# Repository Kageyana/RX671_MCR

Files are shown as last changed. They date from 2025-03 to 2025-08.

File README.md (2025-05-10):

# 初期設定
1. ワークスペースのパスは2バイト文字禁止
2. e2studio プロジェクトの設定→C/C++ビルド→設定<br>ツール設定タブ→Compiler→Includesに<br>
```"${workspace_loc:/${ProjName}/inc}"```<br>
を追加
3. Renesas Extensions for Visual Studio Codeを使う場合<br>
	1. 下記ページを参考に拡張機能をインストールする
	https://qiita.com/y_toyoyama/items/98b7511f9f95343f7a40<br>
	2. launch.json<br>
	serverParametersはデバッガ情報をLLMに渡して整形してもらうと楽
	3. CMakeLists.txt<br>
	CMAKE_CURRENT_SOURCE_DIRに```"inc/*.h"```を追加<br>
	CMAKE_CXX_FLAGSにコンパイラオプションを追加する<br>
	CMAKE_EXE_LINKER_FLAGSにリンカオプションを追加する
	4. .clangd<br>
	下記リポジトリを参考に.clangdとc_cpp_intellisense_helper.hを追加する<br>
	https://github.com/NoMaY-jp/Renesas_VSCode_Extensions_tips_for_Renesas_CC_compilers.git

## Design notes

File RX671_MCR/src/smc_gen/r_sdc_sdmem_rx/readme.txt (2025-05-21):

r_sdc_sdmem_rx (SD Mode SD Memory Card Driver)
=======================

Overview
--------
This driver is a block type device driver to control the SD mode SD memory card using SD Host Interface (SDHI).

Features
--------
* SD Specifications Part 1 Physical Layer Simplified Specifications version 6.00 (SD memory control commands are supported)
* Block type device driver which takes 1 block to be 512 bytes
* SD mode (4 bits) is supported.
* Default speed mode are supported.
* Standard capacity SD memory cards (SDSC) and high-capacity SD memory cards (SDHC, SDXC) are supported.
* Only user areas are supported.
* Only CD pin detection is supported.

File Structure
--------------
r_sdc_sdmem_rx
|   r_sdc_sd_rx_if.h
|   readme.txt
|
+---doc
|   |
|   +---en
|   |   r01an4233ej0301-rx-sdmemory.pdf
|   |
|   +---ja
|       r01an4233jj0301-rx-sdmemory.pdf
|
|
+---src
    |   r_sdc_sd_cd.c
    |   r_sdc_sd_cmd.c
    |   r_sdc_sd_config.c
    |   r_sdc_sd_initialize.c
    |   r_sdc_sd_int.c
    |   r_sdc_sd_open.c
    |   r_sdc_sd_rx_private.h
    |   r_sdc_sd_trans.c
    |   r_sdc_sd_util.c
    |   r_sdc_sd_wrapper.c
    |
    +---mem
            r_sdc_sdmem_initialize.c
            r_sdc_sdmem_param.c
            r_sdc_sdmem_read.c
            r_sdc_sdmem_util.c
            r_sdc_sdmem_wrapper.c
            r_sdc_sdmem_write.c

r_config
    r_sdc_sd_rx_config.h

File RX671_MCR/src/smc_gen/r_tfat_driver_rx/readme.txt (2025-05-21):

r_tfat_driver_rx
=========

Overview
--------
This memory driver interface connects TFAT and Device Drivers(USB etc).
TFAT is a FAT file system which just requires small memory.
TFAT is based on FatFs.
<br/>
Please refer to the
 https://www.renesas.com/mw/tfat

Features
--------
* This memory driver interface connects TFAT and Device Drivers(USB etc).

File Structure
--------------
r_config
    r_tfat_driver_rx_config.h

r_tfat_driver_rx
|   readme.txt
|   r_tfat_driver_rx_if.h
|
+---doc
|   |
|   +---en
|   |   r20an0335ej0261-rx-tfat.pdf
|   +---ja
|       r20an0335jj0261-rx-tfat.pdf
+---src
    |   r_tfat_drv_if.c
    |   r_tfat_drv_if_dev.h
    |
    +---device
        |
        +---sdmem
        |      r_tfat_drv_if_sdmem.c
        +---spi_sdmem
        |      r_tfat_drv_if_spi_sdmem.c
        +---usb
        |      r_tfat_drv_if_usb.c
        +---usb_mini
        |      r_tfat_drv_if_usb_mini.c
        +---mmc
        |      r_tfat_drv_if_mmc.c
        +---serial_flash
               r_tfat_drv_if_flash.c

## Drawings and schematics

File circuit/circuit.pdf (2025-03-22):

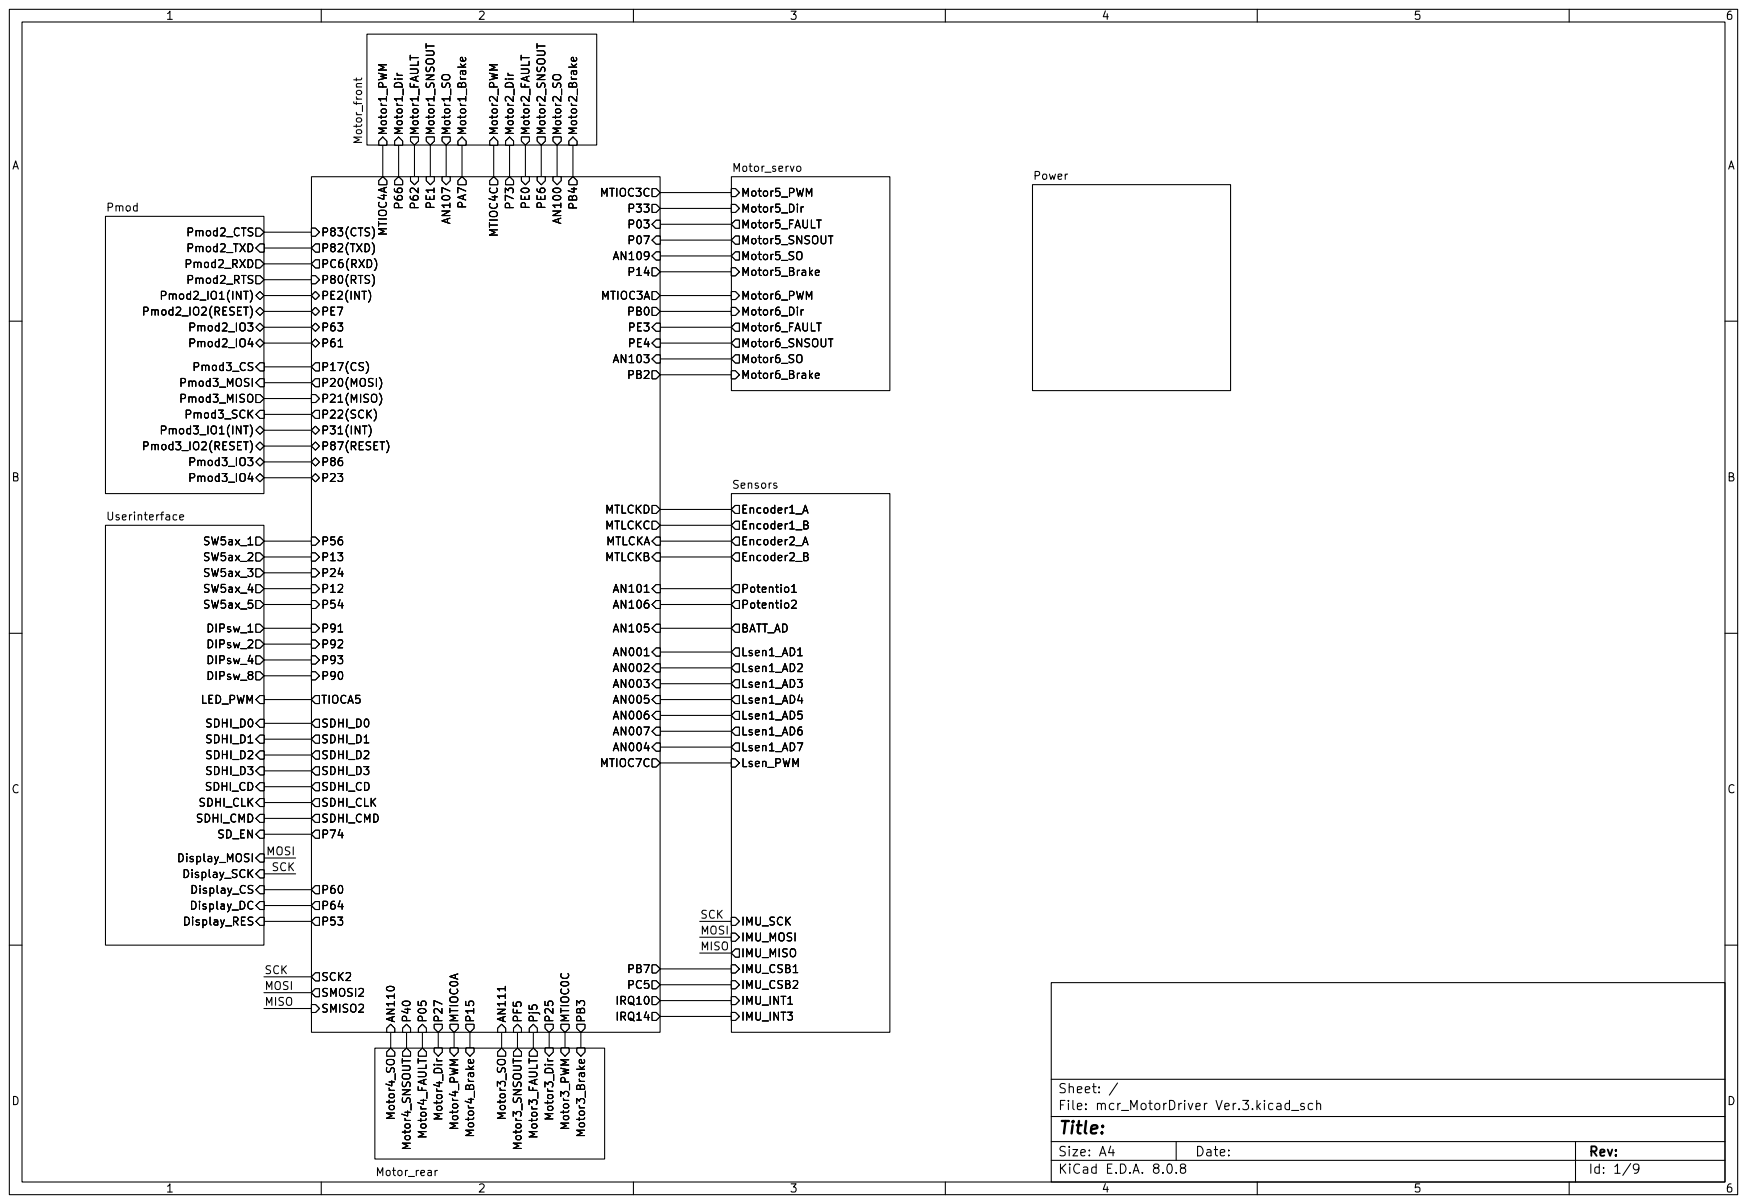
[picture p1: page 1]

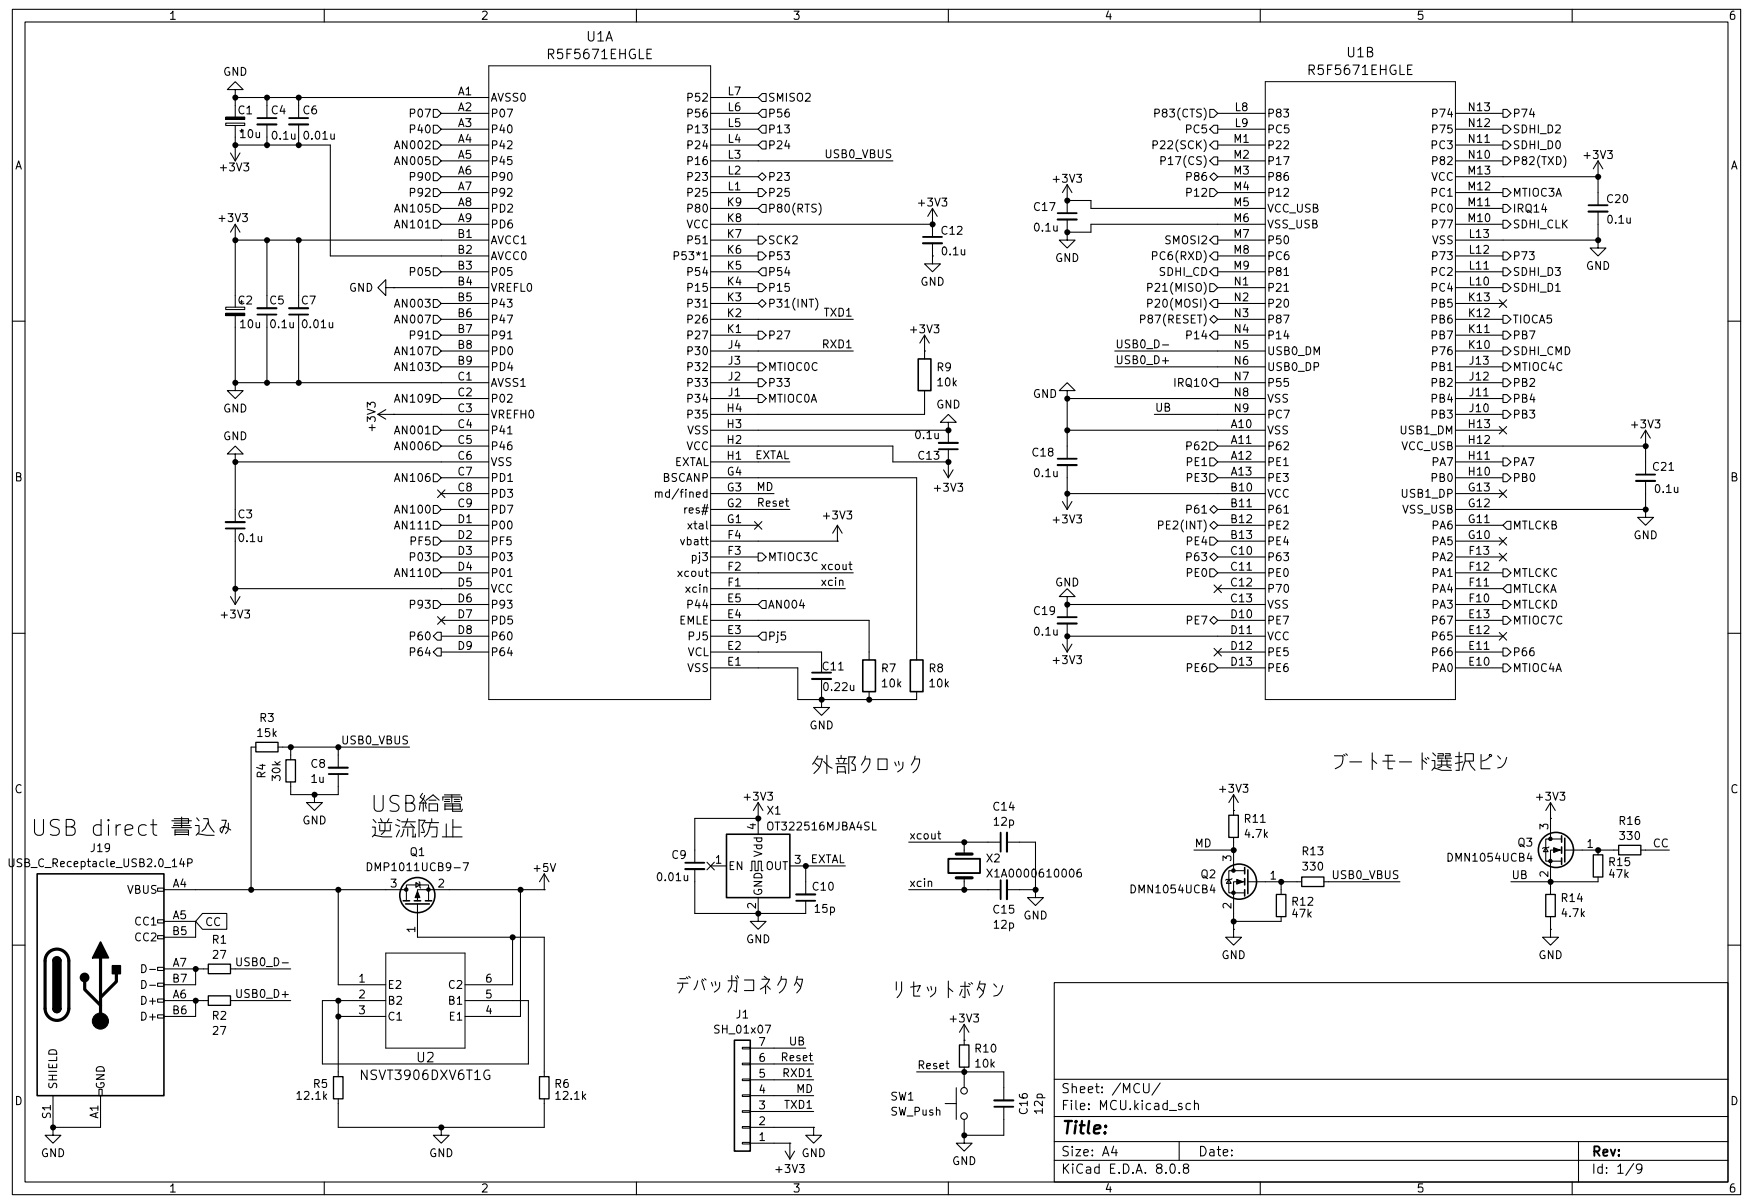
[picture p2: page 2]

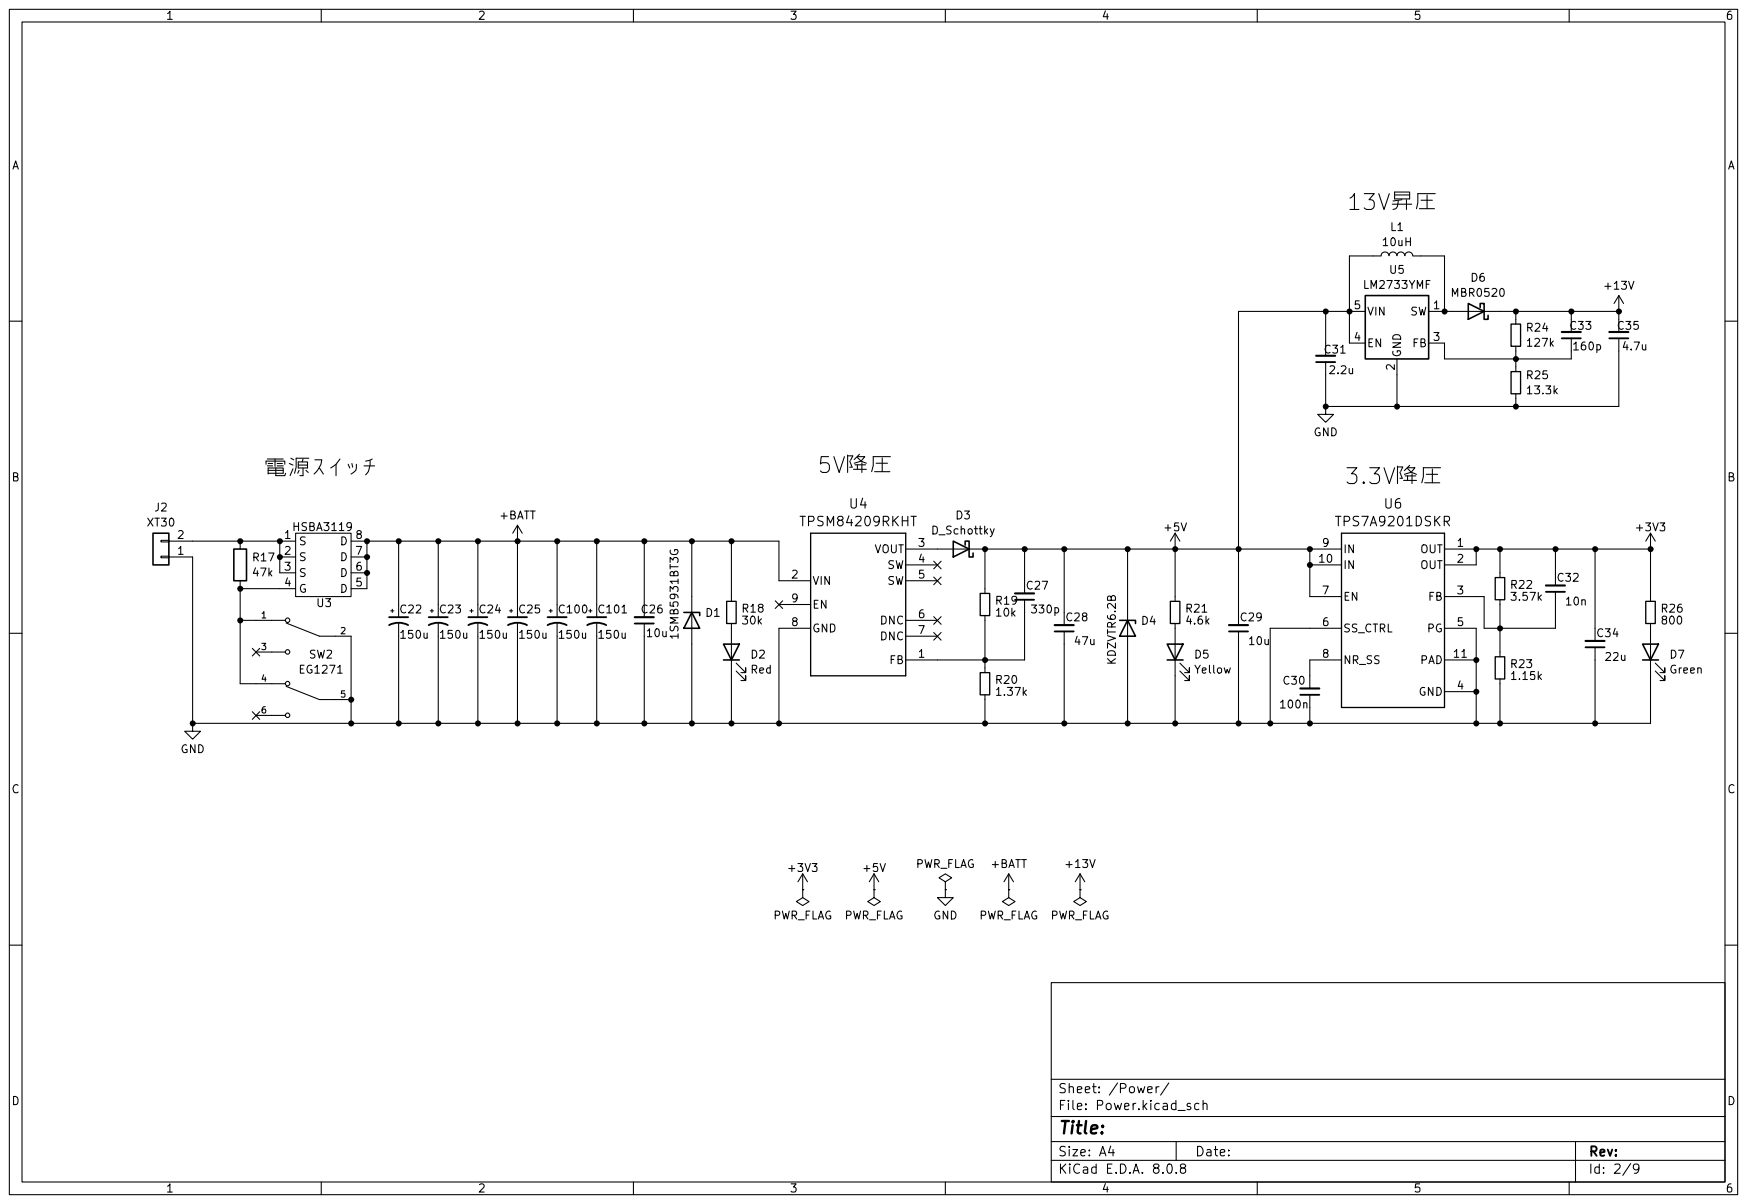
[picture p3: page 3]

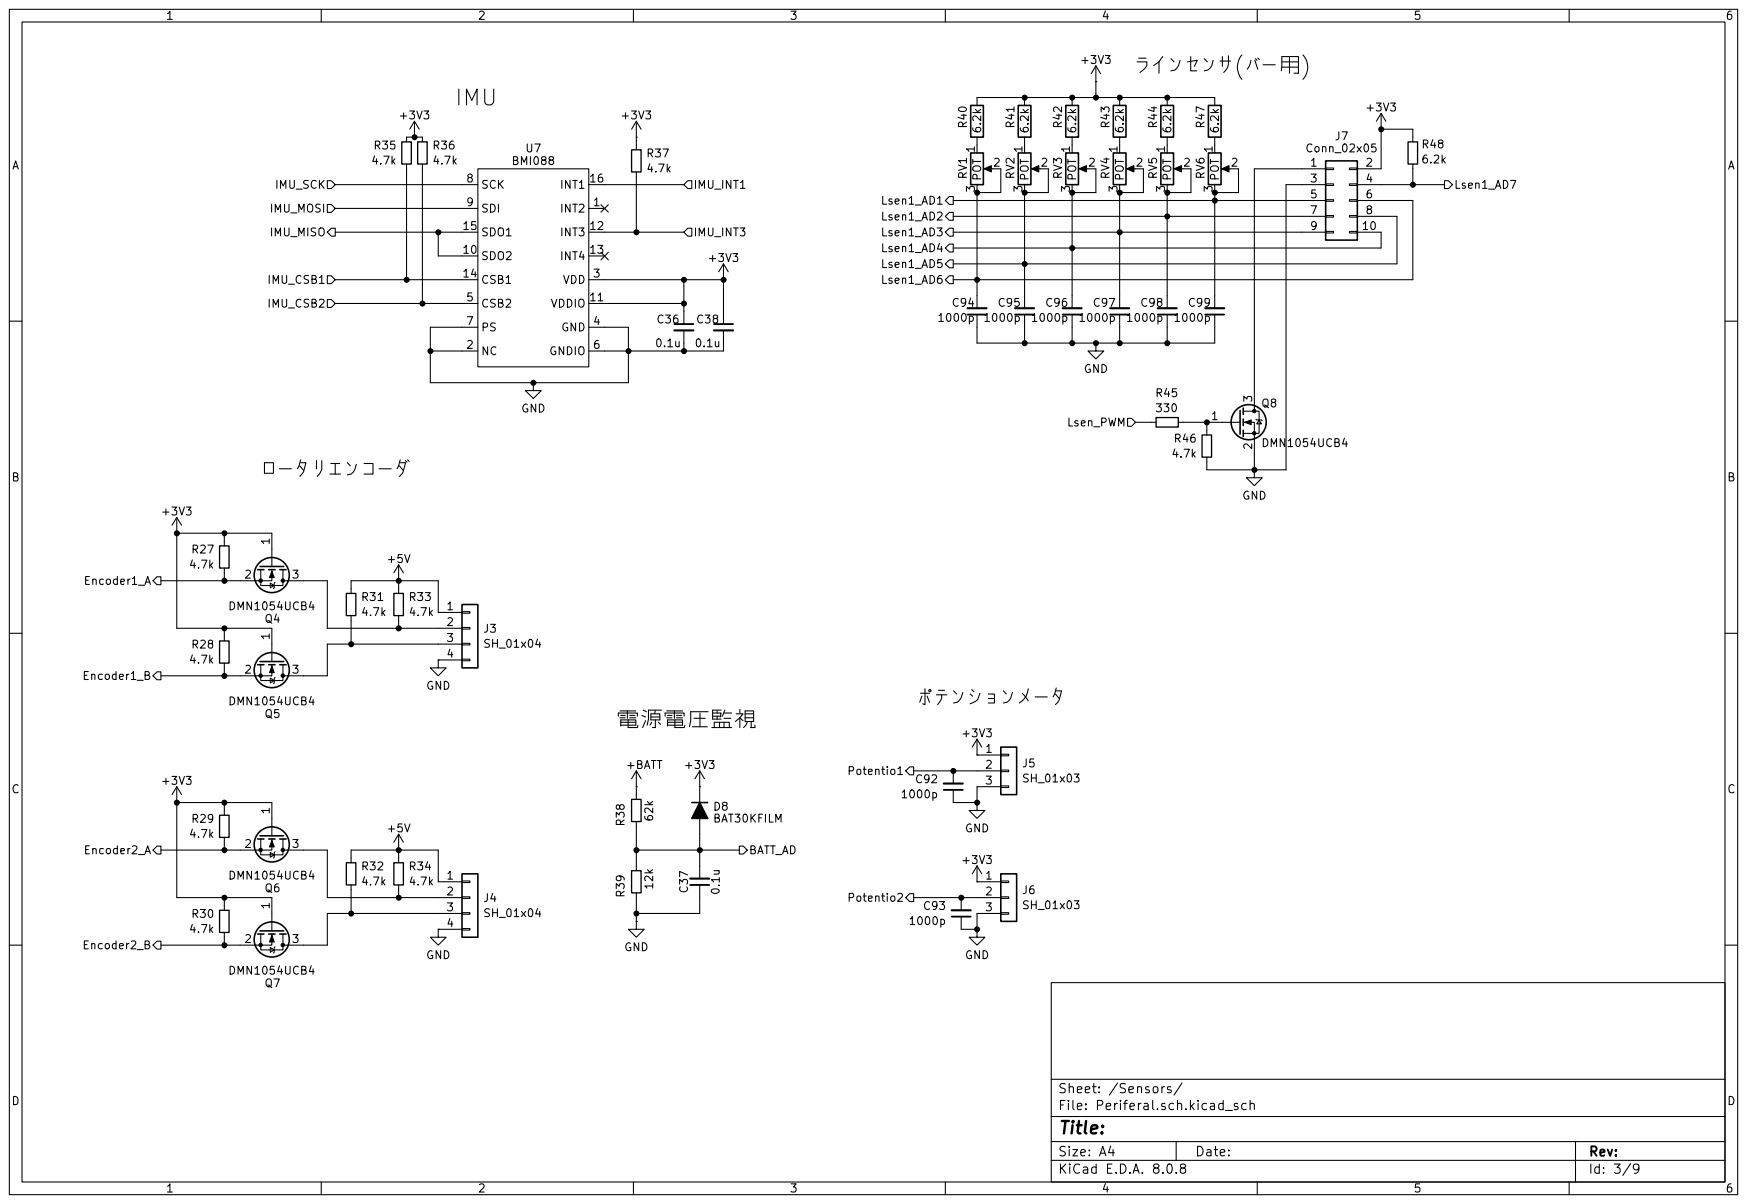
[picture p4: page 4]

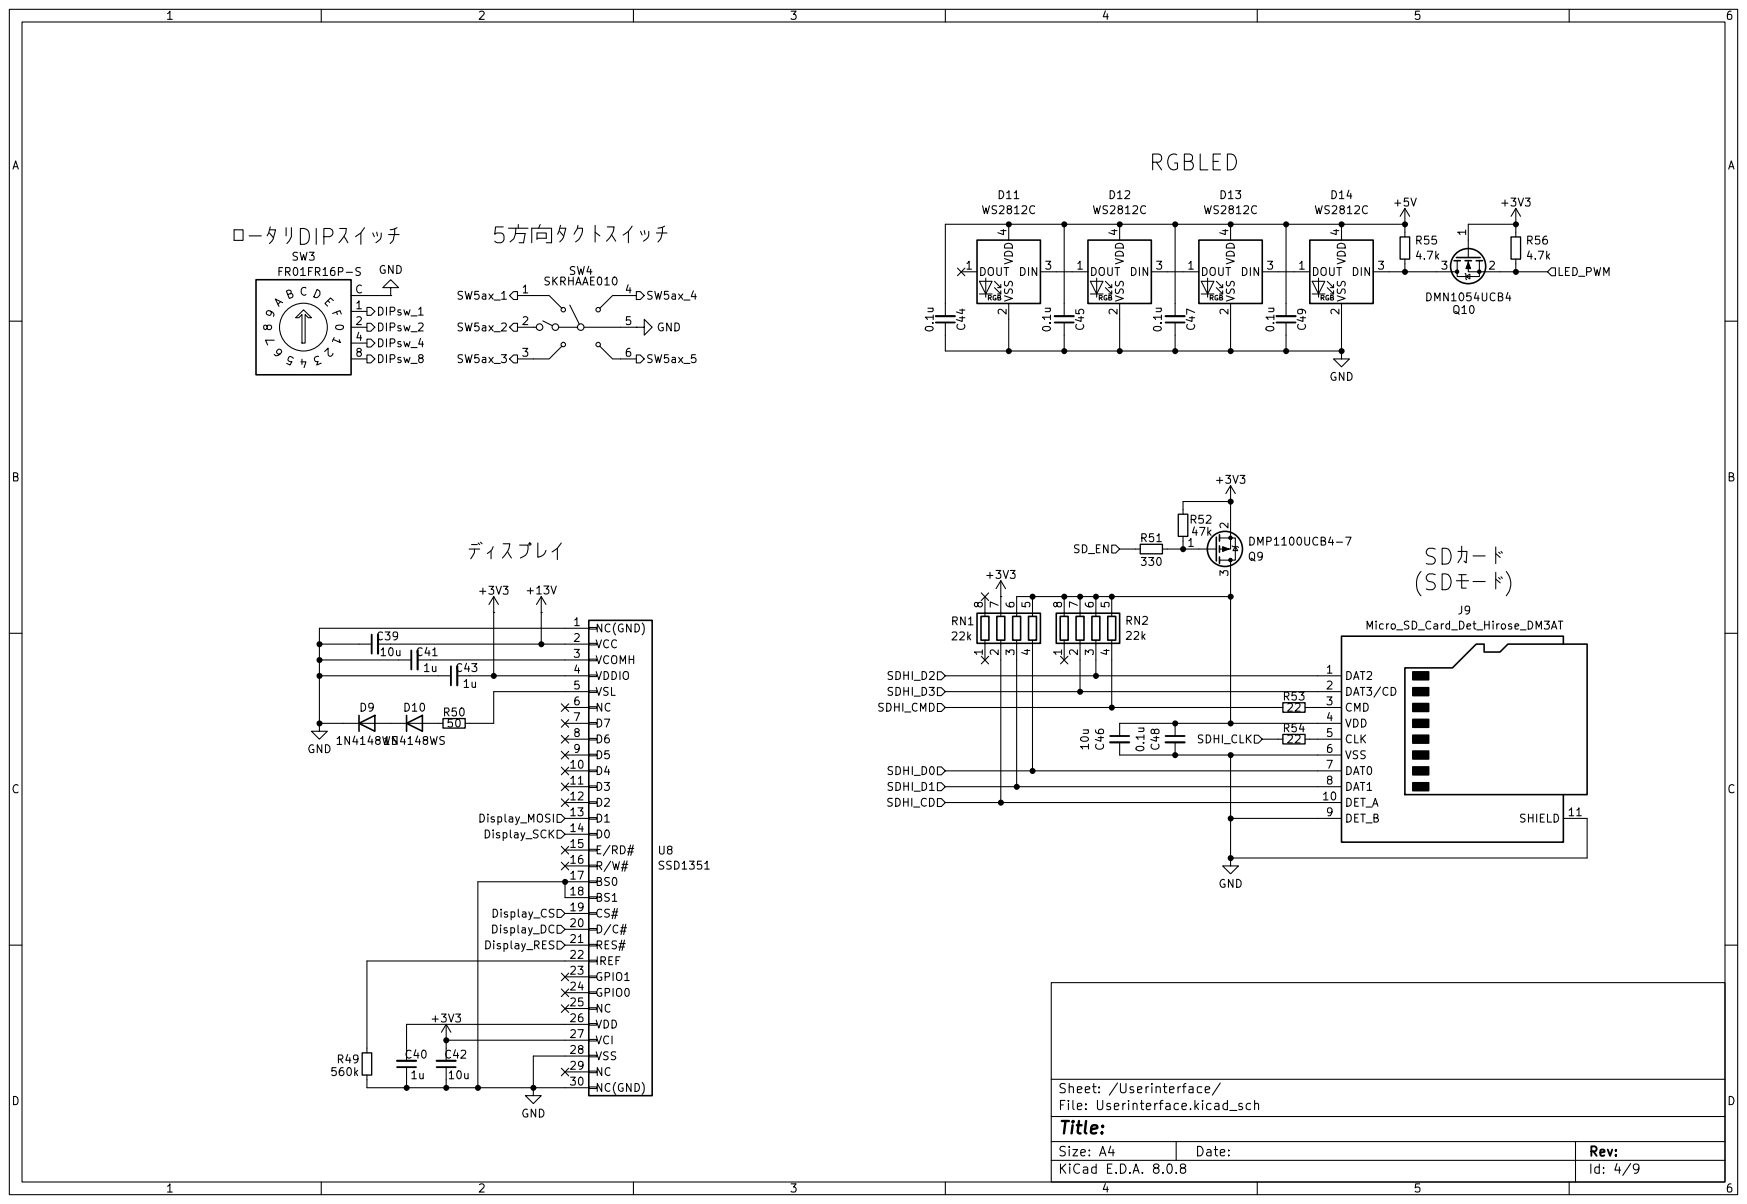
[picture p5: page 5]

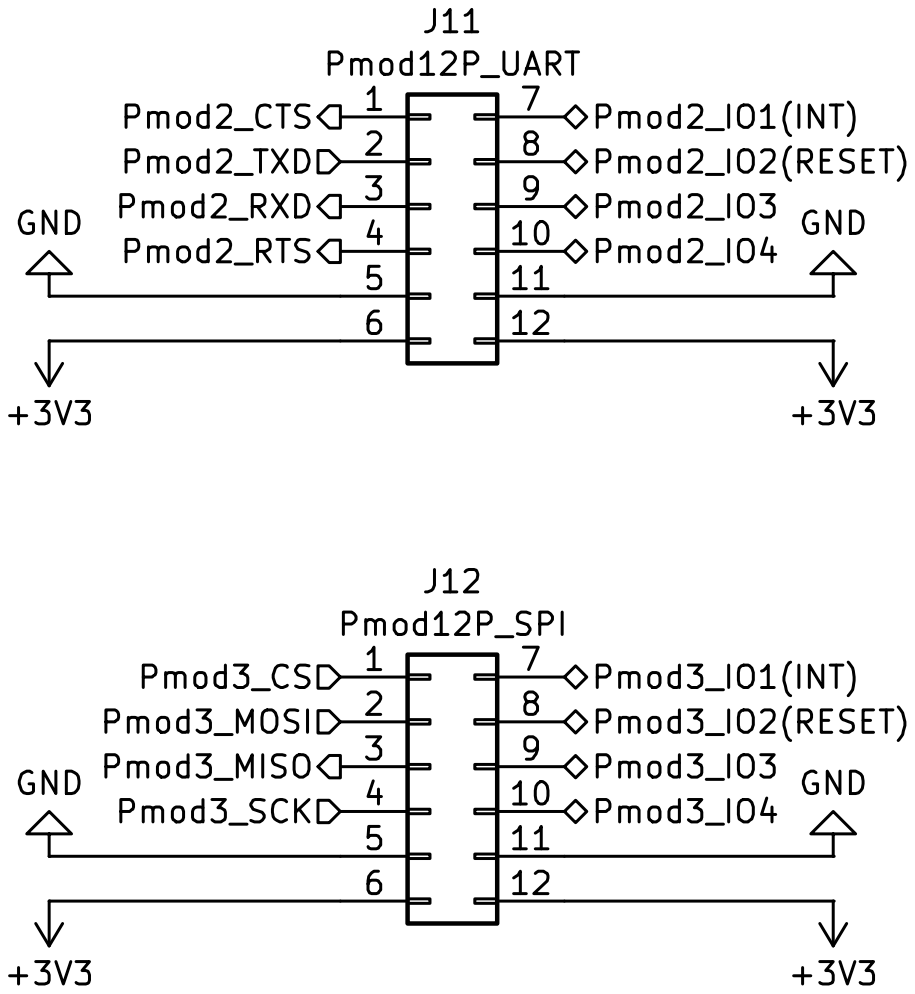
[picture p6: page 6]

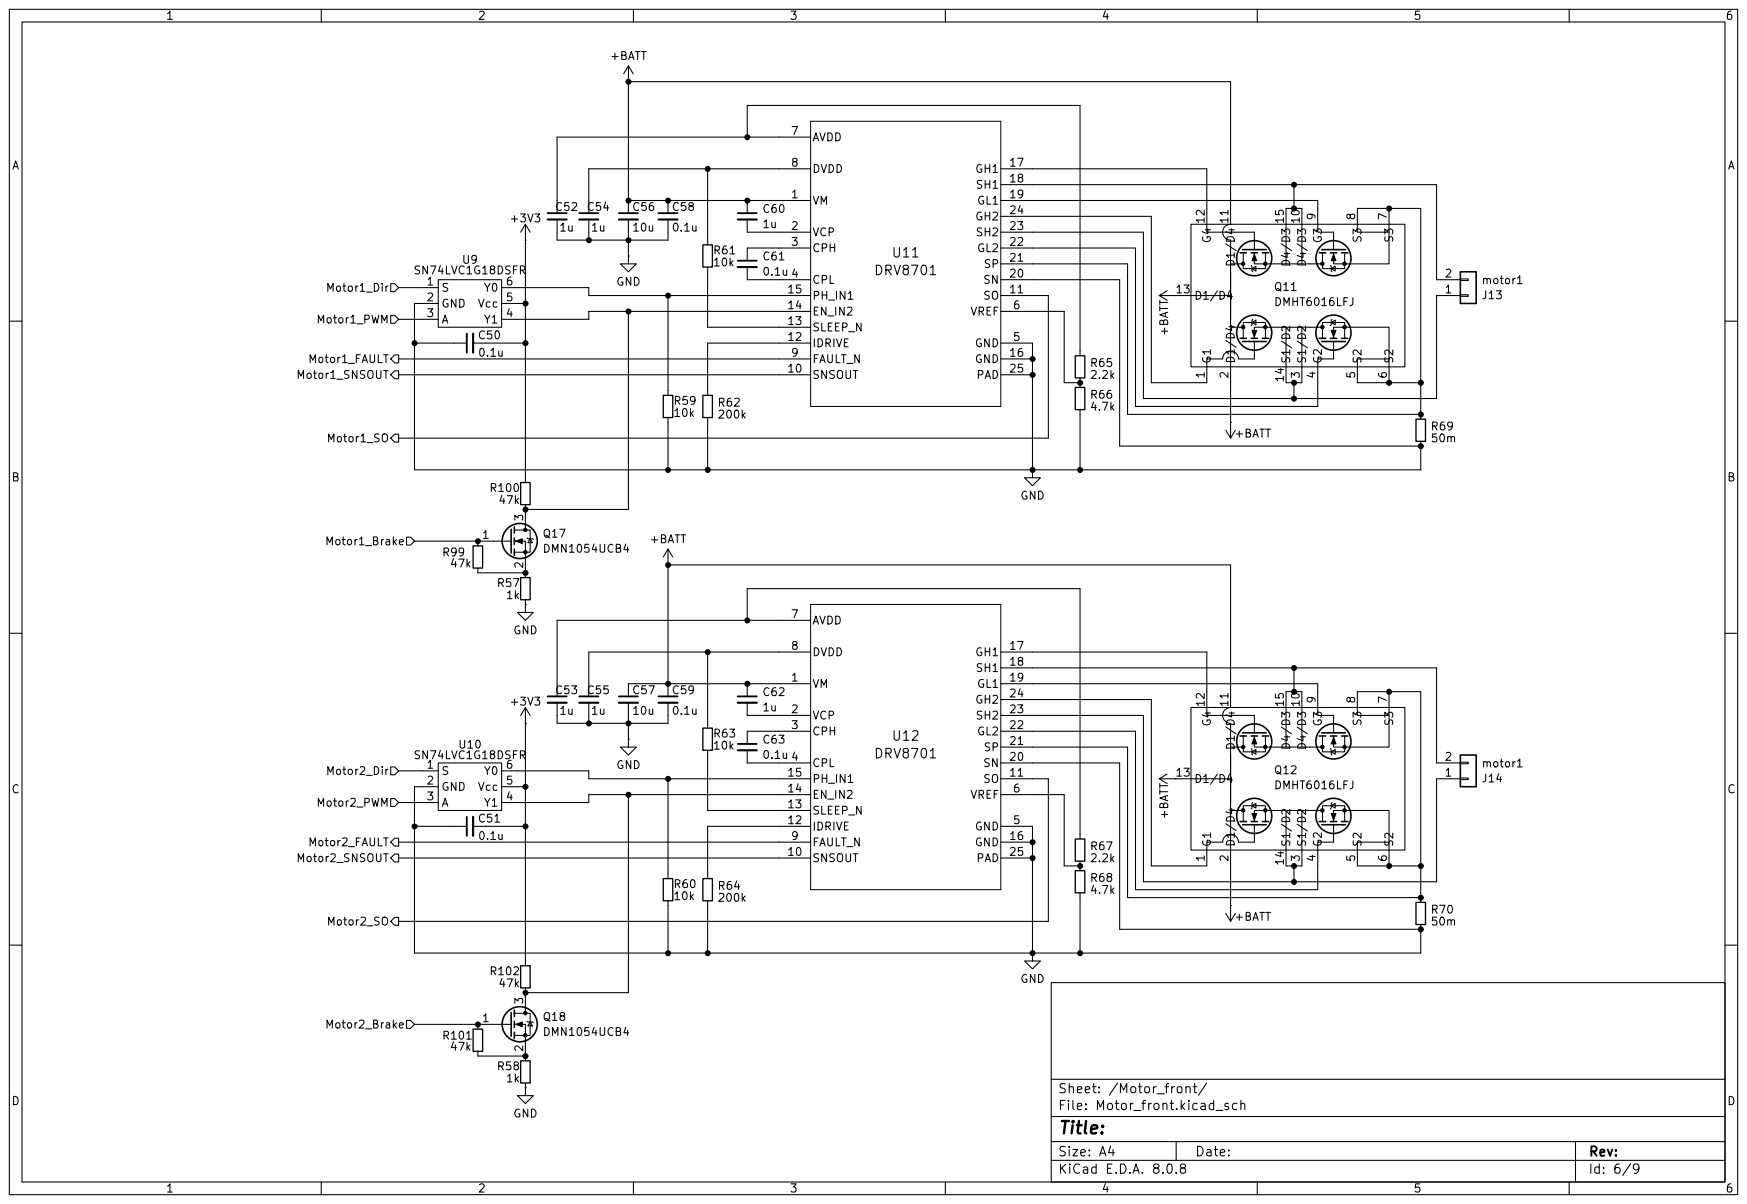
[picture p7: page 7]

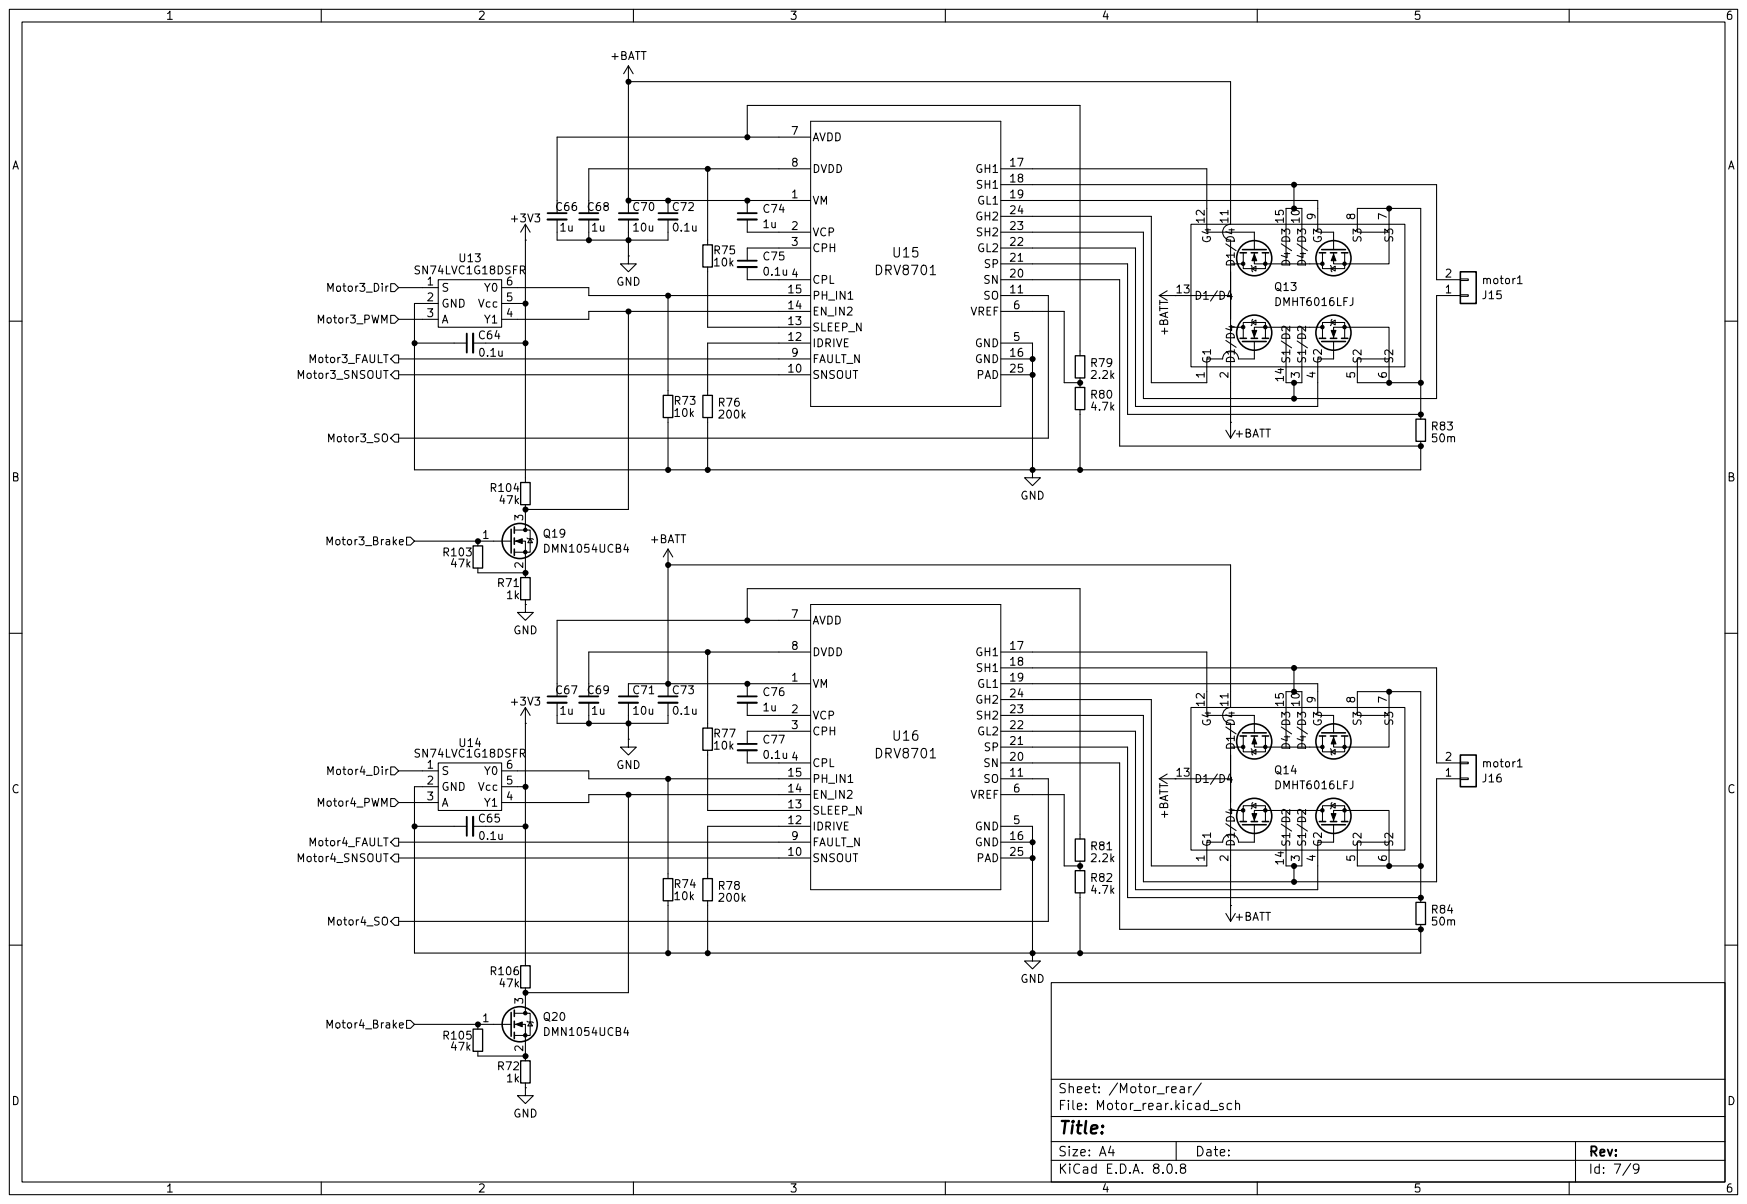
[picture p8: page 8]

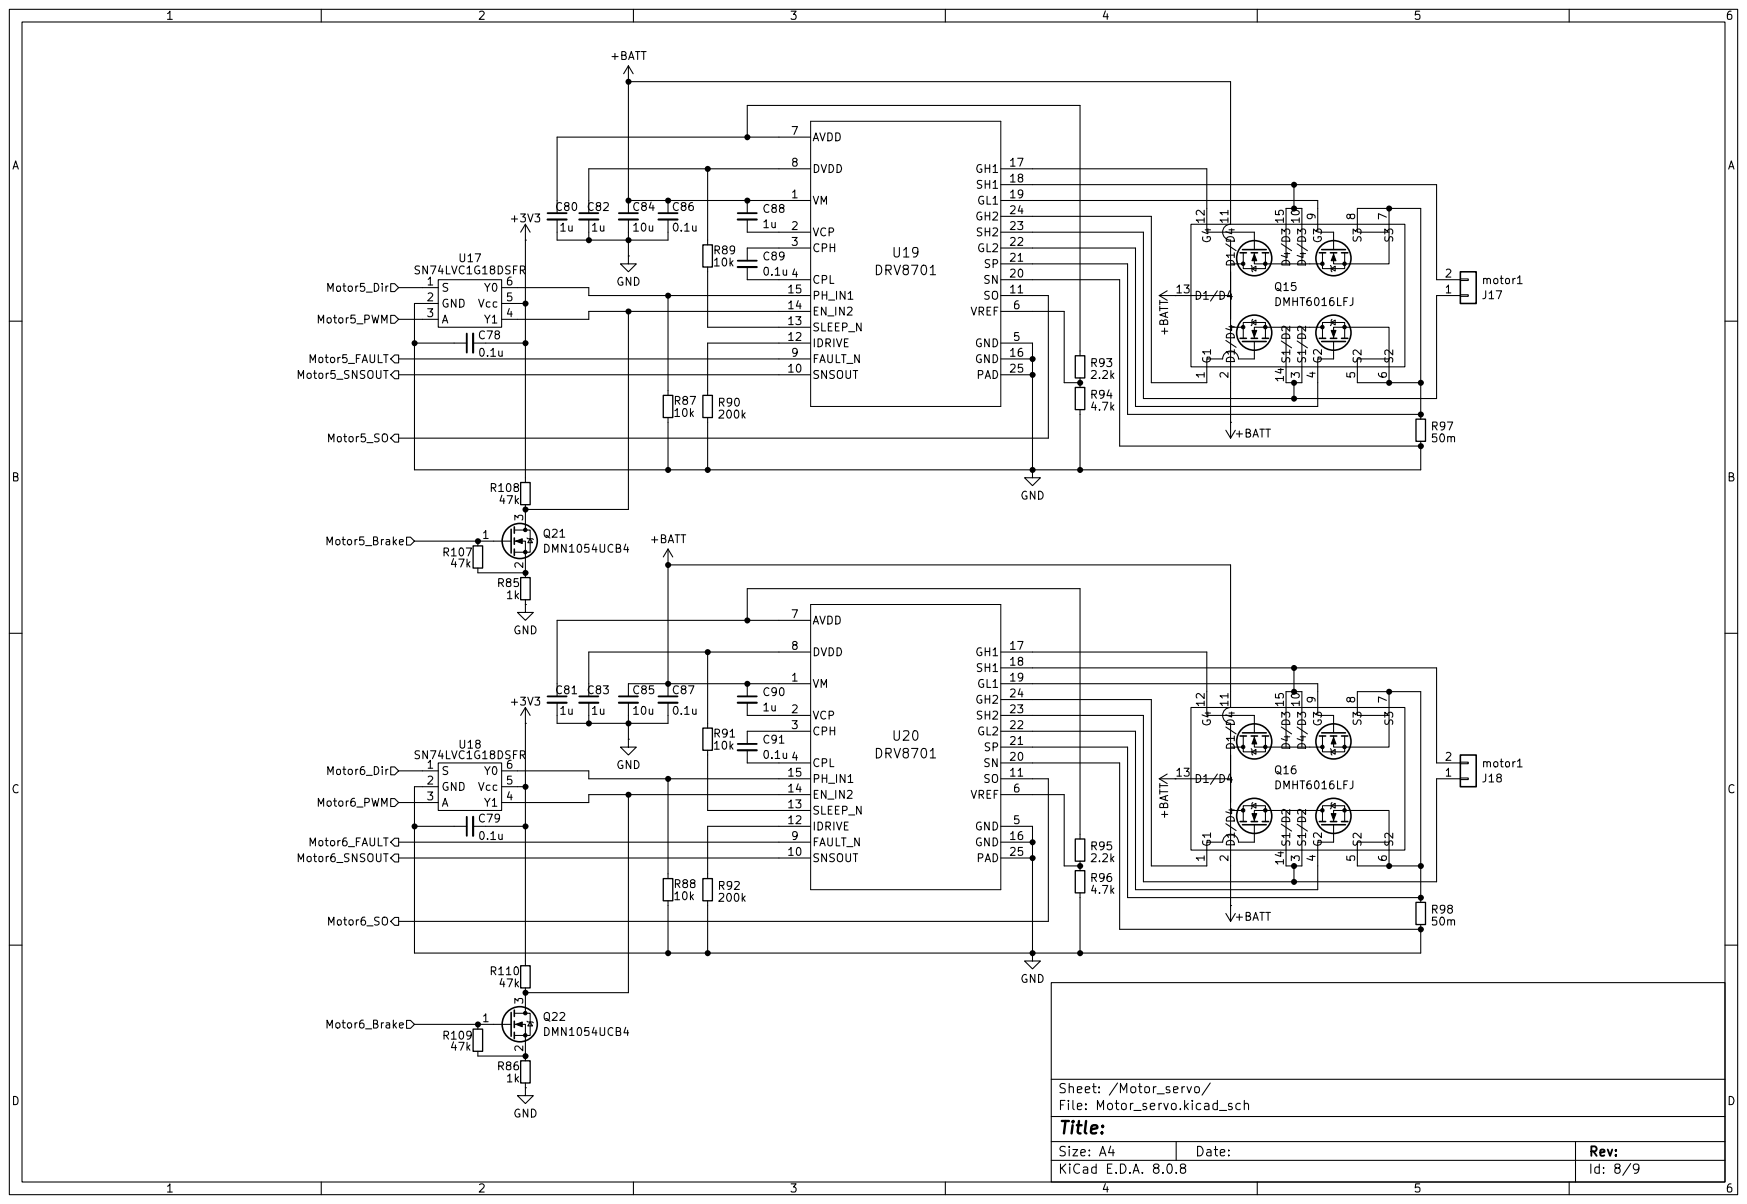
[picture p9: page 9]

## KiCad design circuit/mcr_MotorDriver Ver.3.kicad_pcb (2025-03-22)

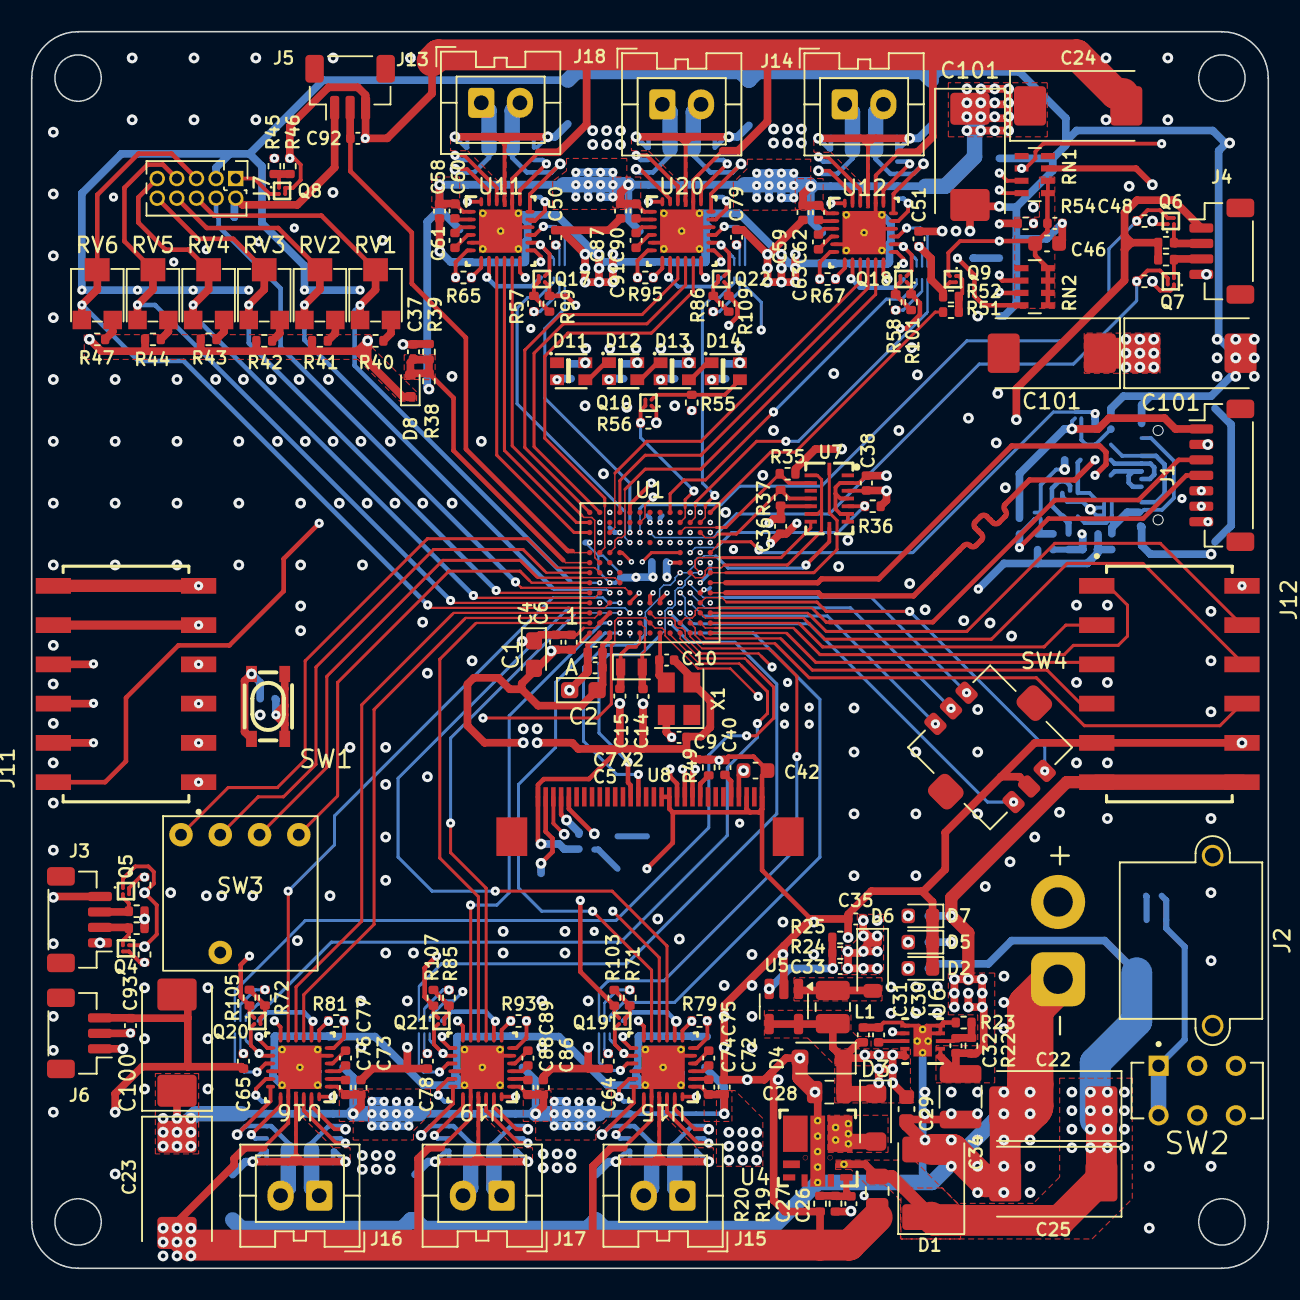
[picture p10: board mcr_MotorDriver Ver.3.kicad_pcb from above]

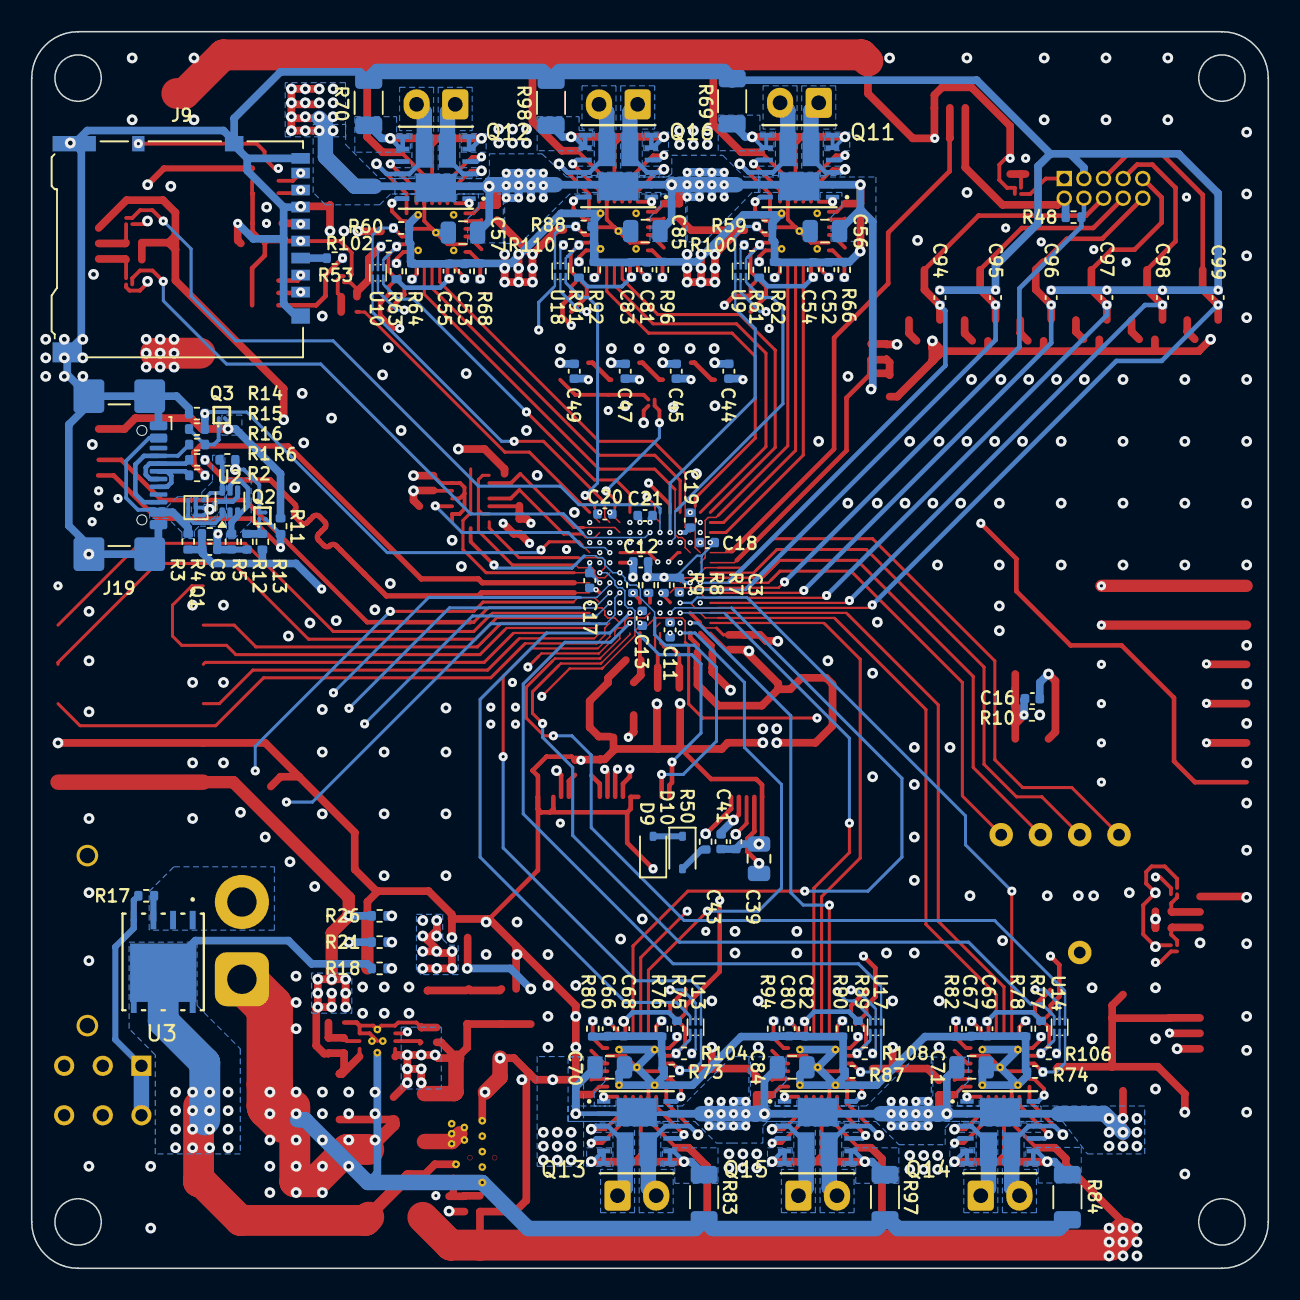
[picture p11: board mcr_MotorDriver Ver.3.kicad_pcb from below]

Board: 6 copper layers, 80.0 x 80.0 mm, 301 parts (122 on the bottom side), 268 nets.

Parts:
C1, C2: 10u; CP_EIA-2012-12_Kemet-R
C3, C4, C5, C12, C13, C17, C18, C19, C20, C21, C36, C37, C38, C44, C45, C47, C48, C49, C50, C51, C58, C59, C61, C63, C64, C65, C72, C73, C75, C77, C78, C79, C86, C87, C89, C91: 0.1u; C_0402_1005Metric
C6, C7, C9: 0.01u; C_0402_1005Metric
C8, C40, C41, C43, C52, C53, C54, C55, C60, C62, C66, C67, C68, C69, C74, C76, C80, C81, C82, C83, C88, C90: 1u; C_0402_1005Metric
C10: 15p; C_0402_1005Metric
C11: 0.22u; C_0402_1005Metric
C14, C15, C16: 12p; C_0402_1005Metric
C22, C23, C24, C25, C100, C101, C101#2, C101#3: 150u; CP_EIA-7343-31_Kemet-D
C26, C39, C56, C57, C70, C71, C84, C85: 10u; C_0805_2012Metric
C27: 330p; C_0402_1005Metric
C28: 47u; C_0805_2012Metric
C29, C42, C46: 10u; C_0603_1608Metric
C30: 100n; C_0402_1005Metric
C31: 2.2u; C_0402_1005Metric
C32: 10n; C_0402_1005Metric
C33: 160p; C_0402_1005Metric
C34: 22u; C_1210_3225Metric
C35: 4.7u; C_0402_1005Metric
C92, C93, C94, C95, C96, C97, C98, C99: 1000p; C_0402_1005Metric
D1: 1SMB5931BT3G; D_2114_3652Metric
D2: Red; LED_0603_1608Metric
D3: D_Schottky; D_SOD-123W
D4: KDZVTR6.2B; D_SOD-123F
D5: Yellow; LED_0603_1608Metric
D6: MBR0520; D_SOD-123
D7: Green; LED_0603_1608Metric
D8: BAT30KFILM; D_SOD-523
D9, D10: 1N4148WS; D_SOD-323
D11, D12, D13, D14: WS2812C; WS2812C-2020
J1: SH_01x07; JST_SH_BM07B-SRSS-TB_1x07-1MP_P1.00mm_Vertical
J2: XT30; AMASS_XT30PW-M_1x02_P2.50mm_Horizontal
J3, J4: SH_01x04; JST_SH_BM04B-SRSS-TB_1x04-1MP_P1.00mm_Vertical
J5, J6: SH_01x03; JST_SH_BM03B-SRSS-TB_1x03-1MP_P1.00mm_Vertical
J7: Conn_02x05; FTSH-105-01-F-D-K
J9: Micro_SD_Card_Det_Hirose_DM3AT; microSD_HC_Hirose_DM3AT-SF-PEJM5
J11: Pmod12P_UART; Pmod_2x06_P2.54mm
J12: Pmod12P_SPI; Pmod_2x06_P2.54mm
J13, J14, J15, J16, J17, J18: motor1; JST_XA_B02B-XASK-1_1x02_P2.50mm_Vertical
J19: USB_C_Receptacle_USB2.0_14P; USB_C_Receptacle_GCT_USB4110
L1: 10uH; L_1008_2520Metric
Q1: DMP1011UCB9-7
Q2, Q3, Q4, Q5, Q6, Q7, Q8, Q10, Q17, Q18, Q19, Q20, Q21, Q22: DMN1054UCB4
Q9: DMP1100UCB4-7; DMN1054UCB4
Q11, Q12, Q13, Q14, Q15, Q16: DMHT6016LFJ; V-DFN5045-12_DIO
R1, R2: 27; R_0402_1005Metric
R3: 15k; R_0402_1005Metric
R4, R18: 30k; R_0402_1005Metric
R5, R6: 12.1k; R_0402_1005Metric
R7, R8, R9, R10, R19, R59, R60, R61, R63, R73, R74, R75, R77, R87, R88, R89, R91: 10k; R_0402_1005Metric
R11, R14, R27, R28, R29, R30, R31, R32, R33, R34, R35, R36, R37, R46, R55, R56, R66, R68, R80, R82, R94, R96: 4.7k; R_0402_1005Metric
R12, R15, R17, R52, R99, R100, R101, R102, R103, R104, R105, R106, R107, R108, R109, R110: 47k; R_0402_1005Metric
R13, R16, R45, R51: 330; R_0402_1005Metric
R20: 1.37k; R_0402_1005Metric
R21: 4.6k; R_0402_1005Metric
R22: 3.57k; R_0402_1005Metric
R23: 1.15k; R_0402_1005Metric
R24: 127k; R_0402_1005Metric
R25: 13.3k; R_0402_1005Metric
R26: 800; R_0402_1005Metric
R38: 62k; R_0402_1005Metric
R39: 12k; R_0402_1005Metric
R40, R41, R42, R43, R44, R47, R48: 6.2k; R_0402_1005Metric
R49: 560k; R_0402_1005Metric
R50: 50; R_0402_1005Metric
R53, R54: 22; R_0402_1005Metric
R57, R58, R71, R72, R85, R86: 1k; R_0402_1005Metric
R62, R64, R76, R78, R90, R92: 200k; R_0402_1005Metric
R65, R67, R79, R81, R93, R95: 2.2k; R_0402_1005Metric
R69, R70, R83, R84, R97, R98: 50m; R_1206_3216Metric
RN1, RN2: 22k; R_Array_Concave_4x0603
RV1, RV2, RV3, RV4, RV5, RV6: POT; ST-32EA
SW1: SW_Push; SKRPABE010
SW2: EG1271; SW_EG1271
SW3: FR01FR16P-S
SW4: SKRHAAE010
U1: R5F5671EHGLE; R5F5671EHGLE-20
U2: NSVT3906DXV6T1G; SOT-563
U3: HSBA3119; IRFH7084TRPBF_INF
U4: TPSM84209RKHT
U5: LM2733YMF; SOT-23-5
U6: TPS7A9201DSKR; TPS7A9201DSKT
U7: BMI088
U8: SSD1351
U9, U10, U13, U14, U17, U18: SN74LVC1G18DSFR
U11, U12, U15, U16, U19, U20: DRV8701
X1: OT322516MJBA4SL; Oscillator_SMD_Abracon_ASE-4Pin_3.2x2.5mm
X2: X1A0000610006; Crystal_SMD_2012-2Pin_2.0x1.2mm

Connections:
+3V3: C1.1, C2.1, C3.1, C4.2, C5.2, C6.2, C7.2, C9.1, C12.1, C13.1, C17.1, C18.2, C19.2, C20.1, C21.1, C32.2, C34.2, C36.1, C38.1, C42.2, C43.2, C50.2, C51.2, C64.2, C65.2, C78.2, C79.2, D8.1 (K), J1.1, J5.1, J6.1, J7.2, J11.6, J11.12, J12.6, J12.12, Q3.3 (D), Q4.1 (G), Q5.1 (G), Q6.1 (G), Q7.1 (G), Q9.2 (S), Q10.1 (G), R9.1, R10.2, R11.2, R22.2, R26.2, R27.2, R28.2, R29.2, R30.2, R35.1, R36.2, R37.2, R40.1, R41.1, R42.1, R43.1, R44.1, R47.1, R48.1, R52.2, R56.2, R100.2, R102.2, R104.2, R106.2, R108.2, R110.2, RN1.7 (R2.2), U1.B1 (AVCC1), U1.B2 (AVCC0), U1.B10 (VCC), U1.C3 (VREFH0), U1.D5 (VCC), U1.D11 (VCC), U1.F4 (vbatt), U1.H2 (VCC), U1.H12 (VCC_USB), U1.K8 (VCC), U1.M5 (VCC_USB), U1.M13 (VCC), U6.1 (OUT), U6.2 (OUT), U7.3 (VDD), U7.11 (VDDIO), U8.4 (VDDIO), U8.27 (VCI), U9.5 (Vcc), U10.5 (Vcc), U13.5 (Vcc), U14.5 (Vcc), U17.5 (Vcc), U18.5 (Vcc), X1.4 (Vdd)
+5V: C27.2, C28.2, C29.2, C31.2, C44.2, C45.2, C47.2, C49.2, D3.1 (K), D4.1 (K), D11.4 (VDD), D12.4 (VDD), D13.4 (VDD), D14.4 (VDD), J3.1, J4.1, L1.1, Q1.2 (S), R19.2, R21.2, R31.2, R32.2, R33.2, R34.2, R55.2, U2.4 (E1), U5.4 (EN), U5.5 (VIN), U6.7 (EN), U6.9 (IN), U6.10 (IN)
+13V: C33.2, C35.2, C39.2, D6.1 (K), R24.2, U8.2 (VCC)
+BATT: C22.1, C23.1, C24.1, C25.1, C26.2, C56.1, C57.1, C58.1, C59.1, C60.1, C62.1, C70.1, C71.1, C72.1, C73.1, C74.1, C76.1, C84.1, C85.1, C86.1, C87.1, C88.1, C90.1, C100.1, C101.1, C101#2.1, C101#3.1, D1.1 (K), Q11.2 (D1/D4), Q11.11 (D1/D4), Q11.13 (D1/D4), Q12.2 (D1/D4), Q12.11 (D1/D4), Q12.13 (D1/D4), Q13.2 (D1/D4), Q13.11 (D1/D4), Q13.13 (D1/D4), Q14.2 (D1/D4), Q14.11 (D1/D4), Q14.13 (D1/D4), Q15.2 (D1/D4), Q15.11 (D1/D4), Q15.13 (D1/D4), Q16.2 (D1/D4), Q16.11 (D1/D4), Q16.13 (D1/D4), R18.2, R38.2, U3.5 (D), U3.6 (D), U3.7 (D), U3.8 (D), U4.2 (VIN), U11.1 (VM), U12.1 (VM), U15.1 (VM), U16.1 (VM), U19.1 (VM), U20.1 (VM)
/MCU/AN001: C99.2, J7.5, RV6.2, RV6.3, U1.C4 (P41)
/MCU/AN002: C98.2, J7.7, RV5.2, RV5.3, U1.A4 (P42)
/MCU/AN003: C97.2, J7.9, RV4.2, RV4.3, U1.B5 (P43)
/MCU/AN004: J7.4, R48.2, U1.E5 (P44)
/MCU/AN005: C96.2, J7.10, RV3.2, RV3.3, U1.A5 (P45)
/MCU/AN006: C95.2, J7.8, RV2.2, RV2.3, U1.C5 (P46)
/MCU/AN007: C94.2, J7.6, RV1.2, RV1.3, U1.B6 (P47)
/MCU/AN100: U1.C9 (PD7), U12.11 (SO)
/MCU/AN101: C92.2, J5.2, U1.A9 (PD6)
/MCU/AN103: U1.B9 (PD4), U20.11 (SO)
/MCU/AN105: C37.2, D8.2 (A), R38.1, R39.2, U1.A8 (PD2)
/MCU/AN106: C93.2, J6.2, U1.C7 (PD1)
/MCU/AN107: U1.B8 (PD0), U11.11 (SO)
/MCU/AN109: U1.C2 (P02), U19.11 (SO)
/MCU/AN110: U1.D4 (P01), U16.11 (SO)
/MCU/AN111: U1.D1 (P00), U15.11 (SO)
/MCU/EXTAL: C10.2, U1.H1 (EXTAL), X1.3 (OUT)
/MCU/IRQ10: U1.N7 (P55), U7.16 (INT1)
/MCU/IRQ14: R37.1, U1.M11 (PC0), U7.12 (INT3)
/MCU/MD: J1.4, Q2.3 (D), R11.1, U1.G3 (md/fined)
/MCU/MTIOC0A: U1.J1 (P34), U14.3 (A)
/MCU/MTIOC0C: U1.J3 (P32), U13.3 (A)
/MCU/MTIOC3A: U1.M12 (PC1), U18.3 (A)
/MCU/MTIOC3C: U1.F3 (pj3), U17.3 (A)
/MCU/MTIOC4A: U1.E10 (PA0), U9.3 (A)
/MCU/MTIOC4C: U1.J13 (PB1), U10.3 (A)
/MCU/MTIOC7C: R45.1, U1.E13 (P67)
/MCU/MTLCKA: Q6.2 (S), R29.1, U1.F11 (PA4)
/MCU/MTLCKB: Q7.2 (S), R30.1, U1.G11 (PA6)
/MCU/MTLCKC: Q5.2 (S), R28.1, U1.F12 (PA1)
/MCU/MTLCKD: Q4.2 (S), R27.1, U1.F10 (PA3)
/MCU/P03: U1.D3 (P03), U19.9 (FAULT_N)
/MCU/P05: U1.B3 (P05), U16.9 (FAULT_N)
/MCU/P07: U1.A2 (P07), U19.10 (SNSOUT)
/MCU/P12: SW4.4, U1.M4 (P12)
/MCU/P13: SW4.2, U1.L5 (P13)
/MCU/P14: Q21.1 (G), R107.1, U1.N4 (P14)
/MCU/P15: Q20.1 (G), R105.1, U1.K4 (P15)
/MCU/P17(CS): J12.1, U1.M2 (P17)
/MCU/P20(MOSI): J12.2, U1.N2 (P20)
/MCU/P21(MISO): J12.3, U1.N1 (P21)
/MCU/P22(SCK): J12.4, U1.M1 (P22)
/MCU/P23: J12.10, U1.L2 (P23)
/MCU/P24: SW4.3, U1.L4 (P24)
/MCU/P25: U1.L1 (P25), U13.1 (S)
/MCU/P27: U1.K1 (P27), U14.1 (S)
/MCU/P31(INT): J12.7, U1.K3 (P31)
/MCU/P33: U1.J2 (P33), U17.1 (S)
/MCU/P40: U1.A3 (P40), U16.10 (SNSOUT)
/MCU/P53: U1.K6 (P53*1), U8.21 (RES#)
/MCU/P54: SW4.6, U1.K5 (P54)
/MCU/P56: SW4.1, U1.L6 (P56)
/MCU/P60: U1.D8 (P60), U8.19 (CS#)
/MCU/P61: J11.10, U1.B11 (P61)
/MCU/P62: U1.A11 (P62), U11.9 (FAULT_N)
/MCU/P63: J11.9, U1.C10 (P63)
/MCU/P64: U1.D9 (P64), U8.20 (D/C#)
/MCU/P66: U1.E11 (P66), U9.1 (S)
/MCU/P73: U1.L12 (P73), U10.1 (S)
/MCU/P74: R51.2, U1.N13 (P74)
/MCU/P80(RTS): J11.4, U1.K9 (P80)
/MCU/P82(TXD): J11.2, U1.N10 (P82)
/MCU/P83(CTS): J11.1, U1.L8 (P83)
/MCU/P86: J12.9, U1.M3 (P86)
/MCU/P87(RESET): J12.8, U1.N3 (P87)
/MCU/P90: SW3.8, U1.A6 (P90)
/MCU/P91: SW3.1, U1.B7 (P91)
/MCU/P92: SW3.2, U1.A7 (P92)
/MCU/P93: SW3.4, U1.D6 (P93)
/MCU/PA7: Q17.1 (G), R99.1, U1.H11 (PA7)
/MCU/PB0: U1.H10 (PB0), U18.1 (S)
/MCU/PB2: Q22.1 (G), R109.1, U1.J12 (PB2)
/MCU/PB3: Q19.1 (G), R103.1, U1.J10 (PB3)
/MCU/PB4: Q18.1 (G), R101.1, U1.J11 (PB4)
/MCU/PB7: R35.2, U1.K11 (PB7), U7.14 (CSB1)
/MCU/PC5: R36.1, U1.L9 (PC5), U7.5 (CSB2)
/MCU/PC6(RXD): J11.3, U1.M8 (PC6)
/MCU/PE0: U1.C11 (PE0), U12.9 (FAULT_N)
/MCU/PE1: U1.A12 (PE1), U11.10 (SNSOUT)
/MCU/PE2(INT): J11.7, U1.B12 (PE2)
/MCU/PE3: U1.A13 (PE3), U20.9 (FAULT_N)
/MCU/PE4: U1.B13 (PE4), U20.10 (SNSOUT)
/MCU/PE6: U1.D13 (PE6), U12.10 (SNSOUT)
/MCU/PE7: J11.8, U1.D10 (PE7)
/MCU/PF5: U1.D2 (PF5), U15.10 (SNSOUT)
/MCU/Pj5: U1.E3 (PJ5), U15.9 (FAULT_N)
/MCU/RXD1: J1.5, U1.J4 (P30)
/MCU/Reset: C16.2, J1.6, R10.1, SW1.2, U1.G2 (res#)
/MCU/SDHI_CD: J9.10 (DET_A), RN1.2 (R2.1), U1.M9 (P81)
/MCU/SDHI_CLK: R54.2, U1.M10 (P77)
/MCU/SDHI_CMD: R53.2, RN2.4 (R4.1), U1.K10 (P76)
/MCU/SDHI_D0: J9.7 (DAT0), RN1.4 (R4.1), U1.N11 (PC3)
/MCU/SDHI_D1: J9.8 (DAT1), RN1.3 (R3.1), U1.L10 (PC4)
/MCU/SDHI_D2: J9.1 (DAT2), RN2.3 (R3.1), U1.N12 (P75)
/MCU/SDHI_D3: J9.2 (DAT3/CD), RN2.2 (R2.1), U1.L11 (PC2)
/MCU/TIOCA5: Q10.2 (S), R56.1, U1.K12 (PB6)
/MCU/TXD1: J1.3, U1.K2 (P26)
/MCU/UB: J1.7, Q3.2 (S), R14.2, R15.1, U1.N9 (PC7)
/MCU/USB0_D+: R2.2, U1.N6 (USB0_DP)
/MCU/USB0_D-: R1.2, U1.N5 (USB0_DM)
/MCU/USB0_VBUS: C8.2, R3.2, R4.2, R13.2, U1.L3 (P16)
/MCU/xcin: C15.1, U1.F1 (xcin), X2.1
/MCU/xcout: C14.1, U1.F2 (xcout), X2.2
/MISO: U1.L7 (P52), U7.10 (SDO2), U7.15 (SDO1)
/MOSI: U1.M7 (P50), U7.9 (SDI), U8.13 (D1)
/SCK: U1.K7 (P51), U7.8 (SCK), U8.14 (D0)
CC: J19.A5 (CC1), J19.B5 (CC2), R16.2
GND: C1.2, C2.2, C3.2, C4.1, C5.1, C6.1, C7.1, C8.1, C9.2, C10.1, C11.2, C12.2, C13.2, C14.2, C15.2, C16.1, C17.2, C18.1, C19.1, C20.2, C21.2, C22.2, C23.2, C24.2, C25.2, C26.1, C28.1, C29.1, C30.1, C31.1, C34.1, C35.1, C36.2, C37.1, C38.2, C39.1, C40.1, C41.1, C42.1, C43.1, C44.1, C45.1, C46.2, C47.1, C48.2, C49.1, C50.1, C51.1, C52.2, C53.2, C54.2, C55.2, C56.2, C57.2, C58.2, C59.2, C64.1, C65.1, C66.2, C67.2, C68.2, C69.2, C70.2, C71.2, C72.2, C73.2, C78.1, C79.1, C80.2, C81.2, C82.2, C83.2, C84.2, C85.2, C86.2, C87.2, C92.1, C93.1, C94.1, C95.1, C96.1, C97.1, C98.1, C99.1, C100.2, C101.2, C101#2.2, C101#3.2, D1.2 (A), D2.1 (K), D4.2 (A), D5.1 (K), D7.1 (K), D9.1 (K), D11.2 (VSS), D12.2 (VSS), D13.2 (VSS), D14.2 (VSS), J1.2, J2.1, J3.4, J4.4, J5.3, J6.3, J7.3, J9.6 (VSS), J9.9 (DET_B), J9.11 (SHIELD), J11.5, J11.11, J12.5, J12.11, J19.A1 (GND), J19.A12 (GND), J19.B1 (GND), J19.B12 (GND), J19.S1 (SHIELD), Q2.2 (S), Q8.2 (S), R4.1, R5.1, R6.1, R7.2, R8.2, R12.1, R14.1, R20.1, R23.1, R25.1, R39.1, R46.1, R49.1, R57.1, R58.1, R59.1, R60.1, R62.1, R64.1, R66.1, R68.1, R69.1, R70.1, R71.1, R72.1, R73.1, R74.1, R76.1, R78.1, R80.1, R82.1, R83.1, R84.1, R85.1, R86.1, R87.1, R88.1, R90.1, R92.1, R94.1, R96.1, R97.1, R98.1, SW1.1, SW2.2, SW2.5, SW3.C, SW4.5, U1.A1 (AVSS0), U1.A10 (VSS), U1.B4 (VREFL0), U1.C1 (AVSS1), U1.C6 (VSS), U1.C13 (VSS), U1.E1 (VSS), U1.G12 (VSS_USB), U1.H3 (VSS), U1.L13 (VSS), U1.M6 (VSS_USB), U1.N8 (VSS), U4.8 (GND), U5.2 (GND), U6.4 (GND), U6.5 (PG), U6.6 (SS_CTRL), U6.11 (PAD), U7.2 (NC), U7.4 (GND), U7.6 (GNDIO), U7.7 (PS), U8.1 (NC(GND)), U8.17 (BS0), U8.18 (BS1), U8.28 (VSS), U8.30 (NC(GND)), U9.2 (GND), U10.2 (GND), U11.5 (GND), U11.16 (GND), U11.20 (SN), U11.25 (PAD), U12.5 (GND), U12.16 (GND), U12.20 (SN), U12.25 (PAD), U13.2 (GND), U14.2 (GND), U15.5 (GND), U15.16 (GND), U15.20 (SN), U15.25 (PAD), U16.5 (GND), U16.16 (GND), U16.20 (SN), U16.25 (PAD), U17.2 (GND), U18.2 (GND), U19.5 (GND), U19.16 (GND), U19.20 (SN), U19.25 (PAD), U20.5 (GND), U20.16 (GND), U20.20 (SN), U20.25 (PAD), X1.2 (GND)
unnamed: D2.2 (A), R18.1
unnamed: D3.2 (A), U4.3 (VOUT)
unnamed: D5.2 (A), R21.1
unnamed: D6.2 (A), L1.2, U5.1 (SW)
unnamed: D7.2 (A), R26.1
unnamed: D10.2 (A), R50.1
unnamed: D9.2 (A), D10.1 (K)
unnamed: D11.3 (DIN), D12.1 (DOUT)
unnamed: D12.3 (DIN), D13.1 (DOUT)
unnamed: D13.3 (DIN), D14.1 (DOUT)
unnamed: D14.3 (DIN), Q10.3 (D), R55.1
unnamed: J2.2, R17.2, U3.1 (S), U3.2 (S), U3.3 (S)
unnamed: J3.2, Q4.3 (D), R33.1
unnamed: J3.3, Q5.3 (D), R31.1
unnamed: J4.2, Q6.3 (D), R34.1
unnamed: J4.3, Q7.3 (D), R32.1
unnamed: J7.1, Q8.3 (D)
unnamed: J9.5 (CLK), R54.1
unnamed: J9.3 (CMD), R53.1
unnamed: C46.1, C48.1, J9.4 (VDD), Q9.3 (D), RN1.5 (R4.2), RN1.6 (R3.2), RN2.5 (R4.2), RN2.6 (R3.2), RN2.7 (R2.2), RN2.8 (R1.2)
unnamed: J13.1, Q11.3 (S1/D2), Q11.14 (S1/D2), U11.23 (SH2)
unnamed: J13.2, Q11.10 (D4/D3), Q11.15 (D4/D3), U11.18 (SH1)
unnamed: J14.1, Q12.3 (S1/D2), Q12.14 (S1/D2), U12.23 (SH2)
unnamed: J14.2, Q12.10 (D4/D3), Q12.15 (D4/D3), U12.18 (SH1)
unnamed: J15.1, Q13.3 (S1/D2), Q13.14 (S1/D2), U15.23 (SH2)
unnamed: J15.2, Q13.10 (D4/D3), Q13.15 (D4/D3), U15.18 (SH1)
unnamed: J16.1, Q14.3 (S1/D2), Q14.14 (S1/D2), U16.23 (SH2)
unnamed: J16.2, Q14.10 (D4/D3), Q14.15 (D4/D3), U16.18 (SH1)
unnamed: J17.1, Q15.3 (S1/D2), Q15.14 (S1/D2), U19.23 (SH2)
unnamed: J17.2, Q15.10 (D4/D3), Q15.15 (D4/D3), U19.18 (SH1)
unnamed: J18.1, Q16.3 (S1/D2), Q16.14 (S1/D2), U20.23 (SH2)
unnamed: J18.2, Q16.10 (D4/D3), Q16.15 (D4/D3), U20.18 (SH1)
unnamed: J19.A6 (D+), J19.B6 (D+), R2.1
unnamed: J19.A7 (D-), J19.B7 (D-), R1.1
unnamed: J19.A4 (VBUS), J19.A9 (VBUS), J19.B4 (VBUS), J19.B9 (VBUS), Q1.3 (D), R3.1, U2.1 (E2)
unnamed: Q1.1 (G), R6.2, U2.6 (C2)
unnamed: Q2.1 (G), R12.2, R13.1
unnamed: Q3.1 (G), R15.2, R16.1
unnamed: Q8.1 (G), R45.2, R46.2
unnamed: Q9.1 (G), R51.1, R52.1
unnamed: Q11.1 (G1), U11.24 (GH2)
unnamed: Q11.4 (G2), U11.22 (GL2)
unnamed: Q11.9 (G3), U11.19 (GL1)
unnamed: Q11.12 (G4), U11.17 (GH1)
unnamed: Q12.1 (G1), U12.24 (GH2)
unnamed: Q12.4 (G2), U12.22 (GL2)
unnamed: Q12.9 (G3), U12.19 (GL1)
unnamed: Q12.12 (G4), U12.17 (GH1)
unnamed: Q13.1 (G1), U15.24 (GH2)
unnamed: Q13.4 (G2), U15.22 (GL2)
unnamed: Q13.9 (G3), U15.19 (GL1)
unnamed: Q13.12 (G4), U15.17 (GH1)
unnamed: Q14.1 (G1), U16.24 (GH2)
unnamed: Q14.4 (G2), U16.22 (GL2)
unnamed: Q14.9 (G3), U16.19 (GL1)
unnamed: Q14.12 (G4), U16.17 (GH1)
unnamed: Q15.1 (G1), U19.24 (GH2)
unnamed: Q15.4 (G2), U19.22 (GL2)
unnamed: Q15.9 (G3), U19.19 (GL1)
unnamed: Q15.12 (G4), U19.17 (GH1)
unnamed: Q16.1 (G1), U20.24 (GH2)
unnamed: Q16.4 (G2), U20.22 (GL2)
unnamed: Q16.9 (G3), U20.19 (GL1)
unnamed: Q16.12 (G4), U20.17 (GH1)
unnamed: Q17.3 (D), R100.1, U9.4 (Y1), U11.14 (EN_IN2)
unnamed: Q17.2 (S), R57.2, R99.2
unnamed: Q18.3 (D), R102.1, U10.4 (Y1), U12.14 (EN_IN2)
unnamed: Q18.2 (S), R58.2, R101.2
unnamed: Q19.3 (D), R104.1, U13.4 (Y1), U15.14 (EN_IN2)
unnamed: Q19.2 (S), R71.2, R103.2
unnamed: Q20.3 (D), R106.1, U14.4 (Y1), U16.14 (EN_IN2)
unnamed: Q20.2 (S), R72.2, R105.2
unnamed: Q21.3 (D), R108.1, U17.4 (Y1), U19.14 (EN_IN2)
unnamed: Q21.2 (S), R85.2, R107.2
unnamed: Q22.3 (D), R110.1, U18.4 (Y1), U20.14 (EN_IN2)
unnamed: Q22.2 (S), R86.2, R109.2
unnamed: R40.2, RV1.1
unnamed: R41.2, RV2.1
unnamed: R42.2, RV3.1
unnamed: R43.2, RV4.1
unnamed: R44.2, RV5.1
unnamed: R47.2, RV6.1
unnamed: R8.1, U1.G4 (BSCANP)
unnamed: R7.1, U1.E4 (EMLE)
unnamed: R9.2, U1.H4 (P35)
unnamed: C11.1, U1.E2 (VCL)
unnamed: R5.2, U2.2 (B2), U2.3 (C1), U2.5 (B1)
unnamed: R17.1, SW2.1, SW2.4, U3.4 (G)
unnamed: C27.1, R19.1, R20.2, U4.1 (FB)
unnamed: C33.1, R24.1, R25.2, U5.3 (FB)
unnamed: C32.1, R22.1, R23.2, U6.3 (FB)
unnamed: C30.2, U6.8 (NR_SS)
unnamed: R49.2, U8.22 (IREF)
unnamed: C41.2, U8.3 (VCOMH)
unnamed: C40.2, U8.26 (VDD)
unnamed: R50.2, U8.5 (VSL)
unnamed: R60.2, U10.6 (Y0), U12.15 (PH_IN1)
unnamed: C52.1, R65.2, U11.7 (AVDD)
unnamed: C61.1, U11.3 (CPH)
unnamed: C61.2, U11.4 (CPL)
unnamed: C54.1, R61.2, U11.8 (DVDD)
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

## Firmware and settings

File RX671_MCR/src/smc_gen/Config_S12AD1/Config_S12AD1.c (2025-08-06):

/*
* Copyright (c) 2016 - 2025 Renesas Electronics Corporation and/or its affiliates
*
* SPDX-License-Identifier: BSD-3-Clause
*/

/***********************************************************************************************************************
* File Name        : Config_S12AD1.c
* Component Version: 1.13.0
* Device(s)        : R5F5671EHxLE
* Description      : This file implements device driver for Config_S12AD1.
***********************************************************************************************************************/

/***********************************************************************************************************************
Pragma directive
***********************************************************************************************************************/
/* Start user code for pragma. Do not edit comment generated here */
/* End user code. Do not edit comment generated here */

/***********************************************************************************************************************
Includes
***********************************************************************************************************************/
#include "r_cg_macrodriver.h"
#include "Config_S12AD1.h"
/* Start user code for include. Do not edit comment generated here */
/* End user code. Do not edit comment generated here */
#include "r_cg_userdefine.h"

/***********************************************************************************************************************
Global variables and functions
***********************************************************************************************************************/
/* Start user code for global. Do not edit comment generated here */
/* End user code. Do not edit comment generated here */

/***********************************************************************************************************************
* Function Name: R_Config_S12AD1_Create
* Description  : This function initializes the S12AD1 channel
* Arguments    : None
* Return Value : None
***********************************************************************************************************************/

void R_Config_S12AD1_Create(void)
{
    /* Cancel S12AD1 module stop state */
    MSTP(S12AD1) = 0U;

    /* Disable and clear interrupt flags of S12AD1 module */
    S12AD1.ADCSR.BIT.ADIE = 0U;
    S12AD1.ADCMPCR.BIT.CMPAIE = 0U;
    S12AD1.ADCMPCR.BIT.CMPBIE = 0U;
    IEN(PERIB, INTB186) = 0U;

    /* Set S12AD1 control registers */
    S12AD1.ADCSR.WORD = _0000_AD_SYNCASYNCTRG_DISABLE | _4000_AD_CONTINUOUS_SCAN_MODE;
    S12AD1.ADDISCR.BYTE = _00_AD_DISCONECT_UNUSED;
    S12AD1.ADADC.BYTE = _03_AD_4_TIME_CONVERSION | _80_AD_AVERAGE_MODE;

    /* Set channels and sampling time */
    S12AD1.ADSSTR0 = _3C_AD1_SAMPLING_STATE_0;
    S12AD1.ADSSTR1 = _3C_AD1_SAMPLING_STATE_1;
    S12AD1.ADSSTR3 = _3C_AD1_SAMPLING_STATE_3;
    S12AD1.ADSSTR5 = _3C_AD1_SAMPLING_STATE_5;
    S12AD1.ADSSTR6 = _3C_AD1_SAMPLING_STATE_6;
    S12AD1.ADSSTR7 = _3C_AD1_SAMPLING_STATE_7;
    S12AD1.ADSSTR9 = _3C_AD1_SAMPLING_STATE_9;
    S12AD1.ADSSTR10 = _3C_AD1_SAMPLING_STATE_10;
    S12AD1.ADSSTR11 = _3C_AD1_SAMPLING_STATE_11;
    S12AD1.ADANSA0.WORD = _0001_AD_ANx00_USED | _0002_AD_ANx01_USED | _0008_AD_ANx03_USED | _0020_AD_ANx05_USED | 
                          _0040_AD_ANx06_USED | _0080_AD_ANx07_USED | _0200_AD_AN109_USED | _0400_AD_AN110_USED | 
                          _0800_AD_AN111_USED;
    S12AD1.ADADS0.WORD = _0001_AD_ANx00_ADD_USED | _0002_AD_ANx01_ADD_USED | _0008_AD_ANx03_ADD_USED | 
                         _0020_AD_ANx05_ADD_USED | _0040_AD_ANx06_ADD_USED | _0080_AD_ANx07_ADD_USED | 
                         _0200_AD_AN109_ADD_USED | _0400_AD_AN110_ADD_USED | _0800_AD_AN111_ADD_USED;
    S12AD1.ADCER.WORD = _0000_AD_RESOLUTION_12BIT | _0000_AD_AUTO_CLEARING_DISABLE | _0000_AD_SELFTDIAGST_DISABLE | 
                        _0000_AD_RIGHT_ALIGNMENT;
    S12AD1.ADCSR.WORD |= _1000_AD_SCAN_END_INTERRUPT_ENABLE;

    /* Set compare control register */
    S12AD1.ADCMPCR.WORD = _0000_AD_WINDOWB_DISABLE | _0000_AD_WINDOWA_DISABLE | _0000_AD_WINDOWFUNCTION_DISABLE;

    /* Set interrupt and priority level */
    ICU.SLIBR186.BYTE = 0x44U;
    IPR(PERIB, INTB186) = _01_AD_PRIORITY_LEVEL1;

    /* Set AN100 pin */
    PORTD.PMR.BYTE &= 0x7FU;
    PORTD.PDR.BYTE &= 0x7FU;
    MPC.PD7PFS.BYTE = 0x80U;

    /* Set AN101 pin */
    PORTD.PMR.BYTE &= 0xBFU;
    PORTD.PDR.BYTE &= 0xBFU;
    MPC.PD6PFS.BYTE = 0x80U;

    /* Set AN103 pin */
    PORTD.PMR.BYTE &= 0xEFU;
    PORTD.PDR.BYTE &= 0xEFU;
    MPC.PD4PFS.BYTE = 0x80U;

    /* Set AN105 pin */
    PORTD.PMR.BYTE &= 0xFBU;
    PORTD.PDR.BYTE &= 0xFBU;
    MPC.PD2PFS.BYTE = 0x80U;

    /* Set AN106 pin */
    PORTD.PMR.BYTE &= 0xFDU;
    PORTD.PDR.BYTE &= 0xFDU;
    MPC.PD1PFS.BYTE = 0x80U;

    /* Set AN107 pin */
    PORTD.PMR.BYTE &= 0xFEU;
    PORTD.PDR.BYTE &= 0xFEU;
    MPC.PD0PFS.BYTE = 0x80U;
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

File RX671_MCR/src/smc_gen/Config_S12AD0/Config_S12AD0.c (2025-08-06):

/*
* Copyright (c) 2016 - 2025 Renesas Electronics Corporation and/or its affiliates
*
* SPDX-License-Identifier: BSD-3-Clause
*/

/***********************************************************************************************************************
* File Name        : Config_S12AD0.c
* Component Version: 1.13.0
* Device(s)        : R5F5671EHxLE
* Description      : This file implements device driver for Config_S12AD0.
***********************************************************************************************************************/

/***********************************************************************************************************************
Pragma directive
***********************************************************************************************************************/
/* Start user code for pragma. Do not edit comment generated here */
/* End user code. Do not edit comment generated here */

/***********************************************************************************************************************
Includes
***********************************************************************************************************************/
#include "r_cg_macrodriver.h"
#include "Config_S12AD0.h"
/* Start user code for include. Do not edit comment generated here */
/* End user code. Do not edit comment generated here */
#include "r_cg_userdefine.h"

/***********************************************************************************************************************
Global variables and functions
***********************************************************************************************************************/
/* Start user code for global. Do not edit comment generated here */
/* End user code. Do not edit comment generated here */

/***********************************************************************************************************************
* Function Name: R_Config_S12AD0_Create
* Description  : This function initializes the S12AD0 channel
* Arguments    : None
* Return Value : None
***********************************************************************************************************************/

void R_Config_S12AD0_Create(void)
{
    /* Cancel S12AD0 module stop state */
    MSTP(S12AD) = 0U;

    /* Disable and clear interrupt flags of S12AD0 module */
    S12AD.ADCSR.BIT.ADIE = 0U;
    S12AD.ADCMPCR.BIT.CMPAIE = 0U;
    S12AD.ADCMPCR.BIT.CMPBIE = 0U;

    /* Set S12AD0 control registers */
    S12AD.ADCSR.WORD = _0000_AD_SYNCASYNCTRG_DISABLE | _4000_AD_CONTINUOUS_SCAN_MODE;
    S12AD.ADDISCR.BYTE = _00_AD_DISCONECT_UNUSED;
    S12AD.ADADC.BYTE = _03_AD_4_TIME_CONVERSION | _80_AD_AVERAGE_MODE;

    /* Set channels and sampling time */
    S12AD.ADSSTR1 = _F0_AD0_SAMPLING_STATE_1;
    S12AD.ADSSTR2 = _F0_AD0_SAMPLING_STATE_2;
    S12AD.ADSSTR3 = _F0_AD0_SAMPLING_STATE_3;
    S12AD.ADSSTR4 = _F0_AD0_SAMPLING_STATE_4;
    S12AD.ADSSTR5 = _F0_AD0_SAMPLING_STATE_5;
    S12AD.ADSSTR6 = _F0_AD0_SAMPLING_STATE_6;
    S12AD.ADSSTR7 = _F0_AD0_SAMPLING_STATE_7;
    S12AD.ADANSA0.WORD = _0002_AD_ANx01_USED | _0004_AD_ANx02_USED | _0008_AD_ANx03_USED | _0010_AD_ANx04_USED | 
                         _0020_AD_ANx05_USED | _0040_AD_ANx06_USED | _0080_AD_ANx07_USED;
    S12AD.ADADS0.WORD = _0002_AD_ANx01_ADD_USED | _0004_AD_ANx02_ADD_USED | _0008_AD_ANx03_ADD_USED | 
                        _0010_AD_ANx04_ADD_USED | _0020_AD_ANx05_ADD_USED | _0040_AD_ANx06_ADD_USED | 
                        _0080_AD_ANx07_ADD_USED;
    S12AD.ADCER.WORD = _0000_AD_RESOLUTION_12BIT | _0000_AD_AUTO_CLEARING_DISABLE | _0000_AD_SELFTDIAGST_DISABLE | 
                       _0000_AD_RIGHT_ALIGNMENT;
    S12AD.ADCSR.WORD |= _0000_AD_SCAN_END_INTERRUPT_DISABLE;

    /* Set compare control register */
    S12AD.ADCMPCR.WORD = _0000_AD_WINDOWB_DISABLE | _0000_AD_WINDOWA_DISABLE | _0000_AD_WINDOWFUNCTION_DISABLE;

    /* Set AN001 pin */
    PORT4.PMR.BYTE &= 0xFDU;
    PORT4.PDR.BYTE &= 0xFDU;
    MPC.P41PFS.BYTE = 0x80U;

    /* Set AN002 pin */
    PORT4.PMR.BYTE &= 0xFBU;
    PORT4.PDR.BYTE &= 0xFBU;
    MPC.P42PFS.BYTE = 0x80U;

    /* Set AN003 pin */
    PORT4.PMR.BYTE &= 0xF7U;
    PORT4.PDR.BYTE &= 0xF7U;
    MPC.P43PFS.BYTE = 0x80U;

    /* Set AN004 pin */
    PORT4.PMR.BYTE &= 0xEFU;
    PORT4.PDR.BYTE &= 0xEFU;
    MPC.P44PFS.BYTE = 0x80U;

    /* Set AN005 pin */
    PORT4.PMR.BYTE &= 0xDFU;
    PORT4.PDR.BYTE &= 0xDFU;
    MPC.P45PFS.BYTE = 0x80U;

    /* Set AN006 pin */
    PORT4.PMR.BYTE &= 0xBFU;
    PORT4.PDR.BYTE &= 0xBFU;
    MPC.P46PFS.BYTE = 0x80U;

    /* Set AN007 pin */
    PORT4.PMR.BYTE &= 0x7FU;
    PORT4.PDR.BYTE &= 0x7FU;
    MPC.P47PFS.BYTE = 0x80U;

    R_Config_S12AD0_Create_UserInit();
}
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

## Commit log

2025-04-10 SSD1351のテスト（表示できない）
    [r_bsp_config_readme.txt]
2025-04-12 SSD1351動作確認 SPIの一回の送信量を1024byteに制限
2025-04-13 ssd1351用のprintfを実装
2025-04-13 BMI088の読み込みできた 数値は不安定
2025-04-14 BMI088の読み込み完了 角速度正常に読み取りできた
2025-04-19 SSD1306のライブラリをSSD1351に変換中
2025-04-19 表示データをバッファに保存して一括で送信するようにした
2025-04-19 文字列の表示ができた
2025-04-27 SSD1351送信関数を数行ずつに分けて送信するように変更
2025-04-29 e2Studioに移行
    [r_bsp_config_readme.txt]
2025-04-30 Renesas Extensions for Visual Studio Codeを試す(動いてない)
2025-04-30 Renesas Extensions for Visual Studio Codeでビルドできた(デバッグはできない)
2025-05-01 デバッグできた
2025-05-01 RX671/R671フォルダ.gitファイルを追加した
    [MCU.kicad_sch, Motor_front.kicad_sch, Motor_rear.kicad_sch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]
2025-05-01 RX671/R671フォルダ.gitファイルを追加した(git_dirを変更)
    [MCU.kicad_sch, Motor_front.kicad_sch, Motor_rear.kicad_sch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]
2025-05-01 RX671/R671フォルダ.gitファイルを追加
    [MCU.kicad_sch, Motor_front.kicad_sch, Motor_rear.kicad_sch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]
2025-05-02 printf時に色が反転する問題を修正
2025-05-02 関数名をローワーキャメルケースに変更した
2025-05-05 ディスプレイバッファの前回値比較をmemcpyに変更
2025-05-08 リポジトリ構造変更
    [MCU.kicad_sch, Motor_front.kicad_sch, Motor_rear.kicad_sch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]
2025-05-10 clangdファイル変更
2025-05-10 README更新
2025-05-10 IMUで加速度、温度の取得ができた IMUキャリブレーションができた
2025-05-11 相補フィルターでピッチ、ロール角度の補正をする(math.hをインクルードできなくて動いてない)
2025-05-11 math.hをインクルードできた 相補フィルターも動いた
2025-05-11 意図しないピクセル描画問題を修正した ダミー受信アドレスとバッファアドレスが被っていたのでバッファ変数にstatic修飾追加
2025-05-11 WS2812Cの動作関数を実装 動かない
2025-05-11 fill関数のカラーが反転する問題を修正
2025-05-12 5方向タクトスイッチとロータリスイッチが使えた
2025-05-21 SDHIを使用したFATファイルシステムでの読み書きができた
2025-05-21 f_printfとf_getsが使えた
2025-05-21 SSD1351とIMUの動作を統合
2025-05-24 SDカード関数を外部ファイルに移動
2025-05-24 sdWorkareaをグローバル変数にしてFatfsのエラー解消
2025-05-25 DMAをFITモジュールに変更
2025-05-25 FatFs+DMAテスト中
2025-05-25 FatFs+DMAが動いた
2025-05-25 IMUのログ取得ができた
2025-05-25 SDカードの電源待ち時間を短縮
2025-05-25 位相係数モードが動いた
2025-05-25 位相計数モードを外部ファイル化
2025-05-26 モータ動かそうとしたけど動かない
2025-05-26 QRコードの表示できた
2025-05-26 SSD1351のコントラスト調整を関数化
2025-05-29 AD変換の取得ができた
    [Motor_front.kicad_sch, Motor_rear.kicad_sch, Motor_servo.kicad_sch]
2025-06-02 PNGのチャンク読み取り機能追加(画像データの解凍は未実装)
2025-06-02 SDカード挿抜割り込みを有効にした
2025-06-04 Fix motor current macros
2025-06-04 Fix battery function name
2025-06-07 Combine AD read and voltage calc
2025-06-07 バッテリ電圧を正しく表示できた
2025-06-07 GUI_MenuSelect内のループを削除
2025-06-08 メインループ中で黒帯が出る現象を修正
2025-06-08 2ページ目を追加
2025-06-08 コントラスト調整中に処理が止まる現象を修正
2025-06-08 コントラスト調整機能の操作性向上
2025-06-09 ディスプレイの色反転機能を追加
2025-06-09 QRコード表示機能を追加
2025-06-10 Add sensor page for rotary switch 0x2
2025-06-11 Add comments to sensor display function
2025-06-11 Add sensor page clear initialization
2025-06-11 インデント調整
2025-06-14 Fix sensor page initialization
2025-06-14 Remove unused sensor reset
2025-06-14 Add sensor selection menus
2025-06-14 Improve sensor menu and add reset
2025-06-14 Remove sensor page reset and show IMU info together
2025-06-14 Show IMU axes labels
2025-06-14 Display IMU axes on separate lines
2025-07-06 モーターが回った
2025-07-06 ラインセンサが動いた(タイマ割り込み、連続スキャンモード)
2025-07-29 一時保存
2025-07-30 右後輪以外回った
2025-07-31 自動生成関数を編集しないでも5ポート回せるようにした
2025-08-01 コードを整理
2025-08-05 Display motor current on sensor page
2025-08-05 Display motor run state and duty percent
2025-08-05 コード整理
2025-08-05 Move sensor menu init flag to function
2025-08-05 センサページ遷移時にボタン状態が残って停止する問題を修正
2025-08-05 バッテリの表示を整数型に変更(浮動小数点表示するとフリーズする)
2025-08-06 コメントを整理
2025-08-06 コメント修正
2025-08-06 自動生成ファイルを無視
2025-08-06 gitignore反映
    [MCU.kicad_sch, Motor_front.kicad_sch, Motor_rear.kicad_sch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]
2025-08-06 robotrace_v2からcontrol.h emergencyStop.hのフォーマットを移植
2025-08-06 ラインセンサ値の表示を見やすく修正
2025-08-06 センサページにポテンションメータを追加
2025-08-06 docs: describe PID tuning workflows
2025-08-07 feat: color PID output when running
2025-08-07 出力時にラインセンサを起動するようにした
2025-08-07 表示位置を修正
2025-08-09 SDかうどにかきこみ
2025-08-09 スタート部分を実装
2025-08-09 通常トレースまで実装
2025-08-10 1周完走した
2025-08-11 reRo杯で1周走った
2025-08-13 Fix BMI088 header include case
2025-08-13 Fix battery voltage divider to use float
2025-08-13 カーブ中のデフ関数を実装
2025-08-13 センサ全灯、消灯時の緊急停止を追加
2025-08-16 RGBLEDが光った
2025-08-17 fix: LEDを右端から順に色変化
2025-08-17 refactor: 右端から順に色が変わるLED制御を統合
2025-08-17 fix: pattern 初期化を2個飛ばしに変更
